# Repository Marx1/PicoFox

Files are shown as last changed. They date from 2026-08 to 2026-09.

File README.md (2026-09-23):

# PicoFox – A Hackable 2m Fox Transmitter
**Pacificon Edition**

*This version is modified from the original by AI6YM. It's designed to be a badge (Defcon/Ham Radio Village Style), doesn't have the expansion header, and runs sightly diffrent firmware.*

----------
**Partially AI CODED**
The modifications to this code was mainly done with AI. I want to be clear about this. 
I'm not a full-time coder, I do understand code, and don't have time to learn this platform for this one-off project.
I *HATE* when people pass off code as theirs when it's been AI/Vibe coded, so I wanted to be super clear here.
I did verify everything and validate the RF purity on my IFR 1900. It is a bit heavy on the deviation, so if you need it to be  more narrow, adjust AUDIO_FM_DEVIATION_HZ and SSTV_FM_DEVIATION_HZ as needed.
-- Trevor KG6MDW

----------

**PicoFox** is an open source fox transmitter for the 2-meter amateur band, built around the
RP2040 microcontroller (the same chip used in the Raspberry Pi Pico). It’s designed to be simple,
functional, and easy to modify.

PicoFox works well as a standalone fox for portable or walking hunts, but it’s also a great platform
for experimentation. There's ample CPU, flash,~~and GPIO~~ available if you want to add features ~~like
sensors or interactivity~~. The transmitter can generate a frequency or phase modulated signal with up
to 3kHz (data) bandwidth.

## Key Features
- Transmits FM in the 144–148 MHz band (ITU Zone 1: 144–146 MHz).
- Configured by editing a text file — no software or terminal needed.
- Transmits 8kHz 16-bit PCM WAV files.
- Automatic Morse code ID with configurable tone and speed.
- RF output > 18dBm at full power. Down to ~ -20dBm with full attenuation.
- Charges over USB.

## Extra Features in the Pacificon Firmware
- Built-in SSTV and APRS transmissions directly from JPEG and text files.
- RTTTL ringtone/song playback from a text file.
- Automatic cycling through WAV, RTTTL, JPEG, and APRS message files.
- Interleaves enabled Voice/Audio, SSTV, and APRS transmission modes.
- Dynamic TX power with a random attenuation value selected within a configured range for each transmission.
- Configurable transmit duty cycle based on the average TX time of recent transmissions.

## REMOVED Features in This Version:
- Expansion header

### Getting One

~~Fully assembled PicoFox units are available from [AI6YM.radio](https://ai6ym.radio/picofox). An
enclosure, battery, and antenna are included. I ship nearly anywhere in the world.~~

You can also build your own - both the hardware and software are open source for non-commercial use.
For commercial inquiries, I am not providing ANY production of the hardware. However for the original design contact [justin@ai6ym.radio](mailto:justin@ai6ym.radio), then load the firmware from this repository.

## Configuration

To configure your PicoFox, connect it to any computer using a micro USB cable. It will appear as a
USB mass storage device (like a flash drive). Open `settings.txt` with a text editor and adjust the
configuration values as needed. Eject the drive, disconnect USB, and power cycle the PicoFox to
apply the new settings.

To reset to factory settings, delete `settings.txt`, eject the drive, disconnect USB, and power
cycle the PicoFox. A default settings file will be regenerated.

### Settings Overview

__THIS SECTION IS STILL UNDER DEVELOPMENT AS THE NEW SOFTWARE IS BEING WRITTEN STILL__

- `CALLSIGN`: Alphanumeric callsign (max 12 characters).
- `ITU_ZONE`: ITU zone where the transmitter operates (`1`, `2`, or `3`).
- `FREQ_MHZ`: Transmit frequency in MHz.
- `DUTY_CYCLE`: Transmit duty cycle percentage (`0–100`). If SSTV mode is on, this must be < 80.
- `ATTENUATION_MODE`: Sets the attenuation mode. `FIXED` uses the `ATTENUATION` setting, `RANDOM` selects a random attenuation value on each transmission.
- `ATTENUATION`: Attenuation level used when `ATTENUATION_MODE=FIXED`. Valid range is `0` - `127`, approximately 0.25dB steps.
- `ATTENUATION_MIN`: Minimum attenuation value used when `ATTENUATION_MODE=RANDOM`. Valid range is `0` - `127` and must be less than `ATTENUATION_MAX`.
- `ATTENUATION_MAX`: Maximum attenuation value used when `ATTENUATION_MODE=RANDOM`. Valid range is `0` - `127` and must be greater than `ATTENUATION_MIN`.
- `FREQUENCY_SHIFTING`: Enables/Disables shifting of the carrier (+/-1k, +/-3k, +/-5k) for Wav/RTTTL transmissions. Does not affact SSTV/ARPS. Default is enabled.
- `MORSE_WPM`: Morse ID speed in words per minute. Maximum is 60wpm, default is 15wpm
- `MORSE_TONE`: Morse tone frequency (100–2000 Hz). Default is 600
- `MORSE_TONE_VOL`: Morse tone volume percentage (`1–100`). Default is 60. Over 60 may cause distortion. Adust as needed to make the Morse sound good.
- `VOICE_ENABLE`: Enables the Voice/Audio file.
- `MORSE_MESSAGE_ENABLE`: Enables Mose code message mode. Messages are read from `morse.txt` one message per line.
- `AUDIO_MODE`: Selects the normal audio source. `WAV` uses `audio.wav`, `audio1.wav`, `audio2.wav`, etc. `RTTTL` uses songs from `songs.txt`.
- `SSTV_ENABLE`: Enables SSTV Mode - YOU MUST set a duty cycle < 80 for this mode to work.
- `SSTV_MODE`: SSTV encoding mode, currently ONLY `ROBOT36` is supported.
- `APRS_ENABLE`: Enables APRS message transmissions. Messages are read from `messages.txt`, one message per line.

**Note:** Invalid or missing values may disable the transmitter or revert to safe defaults.

## Using the Transmitter

After configuring settings as described above. The transmitter will turn on following the
provided settings the next time it is turned on.

The transmitter may be powered by an external USB power supply or the internal battery. The internal
battery charges over USB but no indication is available to show battery charging.

**Note: The power switch must be ON to charge the battery over USB. The transmitter will run on USB
power with the switch OFF but the battery will NOT be charged.**

A full battery will last about five hours at 100% duty cycle with at 1200mAH battery. (The default for a PicoFox)

Transmit cycle is:
  - SSTV (If enabled)
  - APRS (If Enabled)
  - Audio/Morse Message

## Replacing the Audio File

To change the audio transmission, replace the `audio.wav` file in the device’s flash storage. The
audio must be sampled at **8kHz**, **mono** (one channel), and encoded as **signed 16-bit PCM WAV**.

*Note: Audio does not sound very good. I recomend using RTTTL.*

Using **Audacity** (free software available for all major OSs):

1. Set "Project Rate (Hz)" to `8000`.
2. Import, record, or generate your audio.
3. Mix down to a single mono track.
4. Export as WAV using **Signed 16-bit PCM** encoding.
5. Name the file `audio.wav` and copy it to the device.
6. Eject the drive and disconnect USB.
7. Power cycle the PicoFox.

**Notes:**

- Improper format may prevent audio transmission or cause noise to be transmitted instead.
- The audio is transmitted, followed by the morse ID, and then the transmitter turns off if
  `DUTY_CYCLE < 100`. The transmitter DOES take into account SSTV transmit times, as well as APRS.
- To restore the default audio, delete all  `audio.wav`, eject the drive, disconnect USB, and power cycle
  the PicoFox.
- To use muliple audio files, append a 1 to the file name. IE `audio1.wav`, `audio2.wav` etc.
- `FREQUENCY_SHIFTING` can cause the audio to sound bad. This causes the carrier to shift around a bit to make it a bit harder to find the fox.

## SSTV Mode

To use SSTV mode, Upload 320x240 JPEG images named `sstv.jpg` to the flash, and enable SSTV_MODE in the config file.

Make sure you have a valid callsign hard baked into your images. They should be 100% ready to transmit. the Picofox will NOT send a morse ID after SSTV.

**Notes:**
- To use muliple SSTV files, add sditional files with sqequencial numbers to the file name. IE `sstv.jpg`, `sstv1.jpg`, `sstv2.jpg` etc.
- The image MUST be 320x240 otherwise it will skip it.
- Due to timings etc, you may need to use auto-slant or high-precision slant correction. Some android apps (IE Robot36) seem to be OK
- DO NOT use a 100% duty cycle. there needs to be a break inbetween for the Pico to load the image. 99% should be fine if you want basically constant tx. In reality a lower duty cycle like 20-40% is better for harder hunts.

## APRS Mode

To use APRS mode, Upload a text file  named `message.txt` to the flash with a message on each line. To comment out a line use a #. this also means you can't just send a hashtag message. Enable `APRS_ENABLE` in the config file to transmit this mode.

The APRS messages are sent as a plain APRS message sent from the callsign configured in the config file and sent as a broadcast/beacon.  

__DO NOT USE THIS ON 144.39mhz Use a simplex/fox frequency.__

**Notes:**
- The messages are sent DIRECT so they wont be digipeated.

## Morse message Mode

Morse message mode lets you add an extra mose message  before it does the callsign. You can turn off Voice/RTTTL and it will do morse only; or leave voice/rttl on and it will do a voice/rttl -> Morse message -> callsign

To use Morse message mode, Upload a text file  named `message.txt` to the flash with a message on each line. To comment out a line use a #. this also means you can't just send a hashtag message. Enable `MORSE_MESSAGE_ENABLE` in the config file to transmit this mode.

## Random TX power / Attenuation

Included in the config is e settings: `ATTENUATION_MODE` , `ATTENUATION_MIN` and `ATTENUATION_MAX`

if `ATTENUATION_MODE` is set to `RANDOM` on each transmit a random atteunation value will be chosen between `ATTENUATION_MIN` and `ATTENUATION_MAX` and applied to the transmission..

## RTTTL Mode

This was inspired by a discussion had on the [Ham Radio Village](http://hamradiovillage.org/) Discord with delphi and Ralph in #software-shenanigans.

This is built from code from [EvilMog's RTTTL](https://github.com/evilmog/evilmog/tree/master/midijunk) work. As well as others.

To use this mode, enable it, and modify the `VOICE_ENABLE` to `1` and set `AUDIO_MODE` to `RTTTL`.
Then restart. This will create `songs.txt` 

To add songs/tunes, add a song per line following the FlipperMusicTTL format:

FlipperMusicTTL Format

You fan find details of this here, as well as example tunes: https://github.com/neverfa11ing/FlipperMusicRTTTL and https://1j01.github.io/rtttl.js/, you can also adapt some from websites like https://rtttl-hub.io/

**NOTES:**
- `FREQUENCY_SHIFTING` can cause the audio to sound bad. This causes the carrier to shift around a bit to make it a bit harder to find the fox.

## Design Brief

An SI5351 clock generator, locked to a TCXO, provides the RF signal. Modulation is applied in
software by the RP2040. To achieve smooth FM output, modulation is handled on core 1 with
I<sup>2</sup>C running at 1 MHz. Register writes are minimized and no other devices are on
I<sup>2</sup>C0.

Core 0 manages flash operations. Most extensions or new features should run on core 0.

**Note:** Mounting the device as a USB mass storage device will interrupt clean modulation as both
cores are blocked during flash operations. You will need to reset the device after writing to the file system.

The SPI flash device is split into program memory and a FAT16 filesystem. The filesystem contains
a text file for user-supplied settings, an audio file for transmission, and a hash file used to detect changes to the settings file.
Unexpected files are automatically deleted and missing files are re-created from defaults in the
firmware binary.

The design intentionally includes large amounts of free CPU cycles, RAM, and flash so that cool
things can be built on the PicoFox.

## Development Guide

### Build Environment Setup

- Install Arduino IDE >= 2.3.
- Install libraries - Adafruit SPIFlash, Adafruit TinyUSB, Etherkit Si5351.
- Install board package from [my fork of Arduino-Pico](https://github.com/ai6ym/arduino-pico). This
  will be merged upstream eventually but for now you'll need the changes in my fork.
- In `Tools -> Board` select the `Raspberry Pi RP2040/RP2350 Boards -> AI6YM PicoFox`.
- Connect your PicoFox and select the appropriate TTY / COM port.

On Linux it may be necessary to add udev rules for this device. The relevant rules from my system
are below. I have no idea how this works on other operating systems. Mac is probably similar,
Windows should not be used for software developement of any kind (or really anything).

```
# Make an RP2040 in BOOTSEL mode writable by all users, so you can `picotool`
# without `sudo`. 
SUBSYSTEM=="usb", ATTRS{idVendor}=="2e8a", ATTRS{idProduct}=="0003", MODE="0666"

# Symlink an RP2040 running MicroPython from /dev/pico.
#
# Then you can `mpr connect $(realpath /dev/pico)`.
SUBSYSTEM=="tty", ATTRS{idVendor}=="2e8a", ATTRS{idProduct}=="0005", SYMLINK+="pico"

# Adafruit TinyUSB stack.
SUBSYSTEM=="tty", ATTRS{idVendor}=="239a", ATTRS{idProduct}=="cafe", MODE="0666"
SUBSYSTEM=="usb", ATTRS{idVendor}=="239a", ATTRS{idProduct}=="cafe", MODE="0666"
```

### Compilation Settings

- `Flash Size`: `16MB (Sketch: 1MB, FS: 15MB)`
- `CPU Speed`: `200mhz`
- `USB Stack`: `Adafruit TinyUSB`

If needed for some reason you could change the partition layout to give more space for the sketch.
Doing so would destroy all data but the code automatically formats the partition and writes
defaults.

All other settings are fine at default values.

### Recovering a Board/Flashing manually (IE from one of the release files)

In general the UF2 upload process will work fine. Click the upload button, after compilation the IDE
will push the board into UF2 update mode, write the new binary, and then reset the board to normal
operation.

If that doesn't work try the following:
- Reset the board and try again. Just tap the `RESET` button on the board to reset the RP2040.
- Force the device into `BOOTSEL` mode. Hold the `BOOTSEL` button, tap the `RESET` button, and then
  release the `BOOTSEL` button.
- Force the device into `BOOTSEL` mode **AND** change `Tools -> Upload Method` to `PicoTool`.
- When all else fails grab a PicoProbe (or a Pico / Pico2 flashed with the PicoProbe binary),
  connect that to the debug header of the PicoFox, and change `Tools -> Upload Method` to
  `Picoprobe`.
- If all of the above fails, well, he's dead Jim.

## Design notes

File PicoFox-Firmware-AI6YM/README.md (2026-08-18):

# PicoFox – FIRMWARE

A couple notes about the firmware.

To build this, follow the instructions in the main readme.md but you also need the board files from here: https://github.com/ai6ym/arduino-pico

You also need to manually update the python to the latest (as of this commit, that was 3.14.4) as there is a bug with the embeded version that breaks for fat16. You'll need to modify packages/package.pico.indel.template.json to point to a copy of the embedable files from python with no folders. 

I ended up doing this, then having to manually edit a bunch of files and it was a real PITA, IMO, but I'm not a coder so YMMV.

Therefore if you want to build the files on your on, have at it. I'm going to provide the .uf2 files of AI6YM's version pre-compled, and my version so you can flip back and forth.

-Trevor KG6MDW

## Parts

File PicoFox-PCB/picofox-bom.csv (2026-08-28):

Reference | Value | Datasheet | Footprint | Qty | DNP | Description | LCSC Part Number | Manufacturer part number | Manufacturer
BT2 | 3.7V |  | PicofoxLib:JST PH 2 Horizontal | 1 |  | Single-cell battery | C295747 | S2B-PH-SM4-TB(LF)(SN) | JST
C1,C22,C24 | 10nF |  | Capacitor_SMD:C_0402_1005Metric | 3 |  | Unpolarized capacitor, small symbol | C3834692 | GRM1555CYA103GE01D | muRata
C2,C3 | 15pF |  | Capacitor_SMD:C_0402_1005Metric | 2 |  |  | C1548 | 0402CG150J500NT | FH
C4,C23,C68 | 100pF |  | Capacitor_SMD:C_0402_1005Metric | 3 |  | Unpolarized capacitor, small symbol | C1546 | 0402CG101J500NT | FH
C5,C6,C7,C9,C11,C12,C13,C14,C15,C16,C17,C31,C33,C67 | 100nF |  | Capacitor_SMD:C_0402_1005Metric | 14 |  | Unpolarized capacitor, small symbol | C307331 | CL05B104KB54PNC | Samsung
C8,C10 | 1uF |  | Capacitor_SMD:C_0402_1005Metric | 2 |  |  | C52923 | CL05A105KA5NQNC | Samsung
C18,C21,C25,C28 | 24pF |  | Capacitor_SMD:C_0402_1005Metric | 4 |  | Unpolarized capacitor, small symbol | C1864480 | GCM1555C1H240FA16D | muRata
C19,C20,C26,C27 | 43pF |  | Capacitor_SMD:C_0402_1005Metric | 4 |  | Unpolarized capacitor, small symbol | C415393 | GJM1555C1H430FB01D | muRata
C29,C30,C32,C40,C58 | 10uF |  | Capacitor_SMD:C_0603_1608Metric | 5 |  |  | C96446 | CL10A106MA8NRNC | Samsung
D1 | H5VU06B |  | PicofoxLib:DFN0603-2L | 1 |  | Bidirectional transient-voltage-suppression diode, small symbol | C20615780 | H5VU06B | R+O
D2,D4,D5 | LED |  | PicofoxLib:LED 1206 Side View | 3 |  | Light emitting diode | C375479 | E6C1204URAC1UDA | EKINGLUX
D3 | 1N4148WS | https://www.vishay.com/docs/85751/1n4148ws.pdf | Diode_SMD:D_SOD-323 | 1 |  | 75V 0.15A Fast switching Diode, SOD-323 | C2128 | 1N4148WS | JSCJ
FB1,FB2,FB3 | 600 |  | Inductor_SMD:L_0402_1005Metric | 3 |  | Ferrite bead, small symbol | C76886 | BLM15AX601SN1D | muRata
J4 | Conn_Coaxial_Small |  | Connector_Coaxial:SMA_Samtec_SMA-J-P-H-ST-EM1_EdgeMount | 1 |  | coaxial connector (BNC, SMA, SMB, SMC, Cinch/RCA, LEMO, ...) | C5301850 | HYCW12-SMAW0863-1365B | HOAUC
J5 | USB-TYPE-C-018 (DEALON) | https://www.usb.org/sites/default/files/documents/usb_type-c.zip | PicofoxLib:USB_C_Receptacle_HCTL_HC-TYPE-C-16P-01A | 1 |  | USB 2.0-only 16P Type-C Receptacle connector | C2927038 | C2927038 | DEALON
L1,L3,L4,L6 | 68nH |  | Inductor_SMD:L_0402_1005Metric | 4 |  | Inductor, small symbol | C7427064 | AHW1005C-68NJTF | APV
L2,L5 | 75nH |  | Inductor_SMD:L_0402_1005Metric | 2 |  | Murata LQW15AW75NG80D | C1012782 | LQW15AW75NG80D | Murata
L7 | 270nH |  | Inductor_SMD:L_0402_1005Metric | 1 |  | Inductor | C22400372 | YWIF1005-R27K | YJYCOIN
Q1 | AO3407A | http://www.aosmd.com/pdfs/datasheet/AO3401A.pdf | Package_TO_SOT_SMD:SOT-23 | 1 |  | -4.0A Id, -30V Vds, P-Channel MOSFET, SOT-23 | C7436553 | AO3407A | FUXINSEMI
R1 | 100KR |  | Resistor_SMD:R_0402_1005Metric | 1 |  | Resistor | C25741 | 0402WGF1003TCE | UNI-ROYAL
R2,R8,R37,R38 | 10KR |  | Resistor_SMD:R_0402_1005Metric | 4 |  | Resistor | C25744 | 0402WGF1002TCE | UNI-ROYAL
R3,R4 | 33R |  | Resistor_SMD:R_0402_1005Metric | 2 |  |  | C25105 | 0402WGF330JTCE | UNI-ROYAL
R5,R6,R7,R36 | 1KR |  | Resistor_SMD:R_0402_1005Metric | 4 |  |  | C11702 | 0402WGF1001TCE | UNI-ROYAL
R9,R10 | 2.2KR |  | Resistor_SMD:R_0402_1005Metric | 2 |  | Resistor | C25879 | 0402WGF2201TCE | UNI-ROYAL
R12,R40 | 120R |  | Resistor_SMD:R_0402_1005Metric | 2 |  | Resistor | C25079 | 0402WGF1200TCE | UNI-ROYAL
R13,R14,R39 | 294R |  | Resistor_SMD:R_0402_1005Metric | 3 |  | Resistor | C852689 | RT0402BRD07294RL | YAGEO
R15 | 17.4R |  | Resistor_SMD:R_0402_1005Metric | 1 |  | Resistor - Thin Film | C284383 | ARG02FTC17R4 | Viking
R27,R28 | 5.11KR |  | Resistor_SMD:R_0402_1005Metric | 2 |  |  | C5126228 | FRC0402F5111TS | FOJAN
SW1,SW2 |  |  | Button_Switch_SMD:SW_Push_SPST_NO_Alps_SKRK | 2 |  | Push button switch, generic, two pins | C720477 | TS-1088-AR02016 | XUNPU
SW3 | SK-12D15-G030 |  | PicofoxLib:SW_Slide_SPDT_Angled_CK_OS102011MA1Q | 1 |  | Switch, single pole double throw | C7544904 | SK-12D15-G030 | G-Switch
U1 | BVA1761 |  | Package_DFN_QFN:QFN-24-1EP_4x4mm_P0.5mm_EP2.5x2.5mm | 1 |  | Berex BVA1761 | C38240054 | BVA1761 | BeRex Corp
U2 | W25Q128JVS | http://www.winbond.com/resource-files/w25q128jv_dtr%20revc%2003272018%20plus.pdf | Package_SO:SOIC-8_5.23x5.23mm_P1.27mm | 1 |  |  | C97521 | W25Q128JVSIQ | Winbond
U3 | RP2040 |  | RP2040_minimal:RP2040-QFN-56 | 1 |  |  | C2040 | RP2040 | Raspberry Pi
U4 | Si5351A-B-GT | https://www.silabs.com/documents/public/data-sheets/Si5351-B.pdf | Package_SO:MSOP-10_3x3mm_P0.5mm | 1 |  | I2C Programmable Any-Frequency CMOS Clock Generator, MSOP-8 | C504891 | SI5351A-B-GTR | SILICON LABS
U15 | USBLC6-2SC6 | https://www.st.com/resource/en/datasheet/usblc6-2.pdf | Package_TO_SOT_SMD:SOT-23-6 | 1 |  | Very low capacitance ESD protection diode, 2 data-line, SOT-23-6 | C5180249 | USBLC6-2SC6-ES | ElecSuper
U16 | BQ21040DBVR | http://www.ti.com/lit/gpn/bq21040 | PicofoxLib:SOT95P280X145-6N | 1 |  | 0.8A Single Input Single-Cell Li-Ion and Li-Pol Battery Charger | C202311 | BQ21040DBVR | TI
U19 | ME6217C33M5G | https://jlcpcb.com/api/file/downloadByFileSystemAccessId/8588884515300892672 | Package_TO_SOT_SMD:SOT-23-5 | 1 |  | -40℃~+85℃ 1 100uA 180mV@(300mA) 3.3V 6.5V 65dB@(1kHz) 800mA Fixed Over Temperature Protection Positive SOT-23-5 Voltage Regulators - Linear, Low Drop Out (LDO) Regulators ROHS | C427602 | ME6217C33M5G | MICRONE
Y1 | ABM8-272-T3 |  | Crystal:Crystal_SMD_3225-4Pin_3.2x2.5mm | 1 |  |  | C20625731 | ABM8-272-T3 | ABRACON
Y2 | TG2016SMN_25.0000M-MCGNNM0 | https://www.mouser.in/datasheet/2/137/TG2016SMN_en-2584166.pdf | AI6YM:TG2016SMN250000MMCGNNM0 | 1 |  | TCXO Oscillators TG2016SMN 25.0000M-MCGNNM0: TCXO 2.8V 3.3V 0.5PPM -40 85C NON O/E 1K TR | C20340789 | TG2016SMN 25.0000M-MCGNNM0 | EPSON

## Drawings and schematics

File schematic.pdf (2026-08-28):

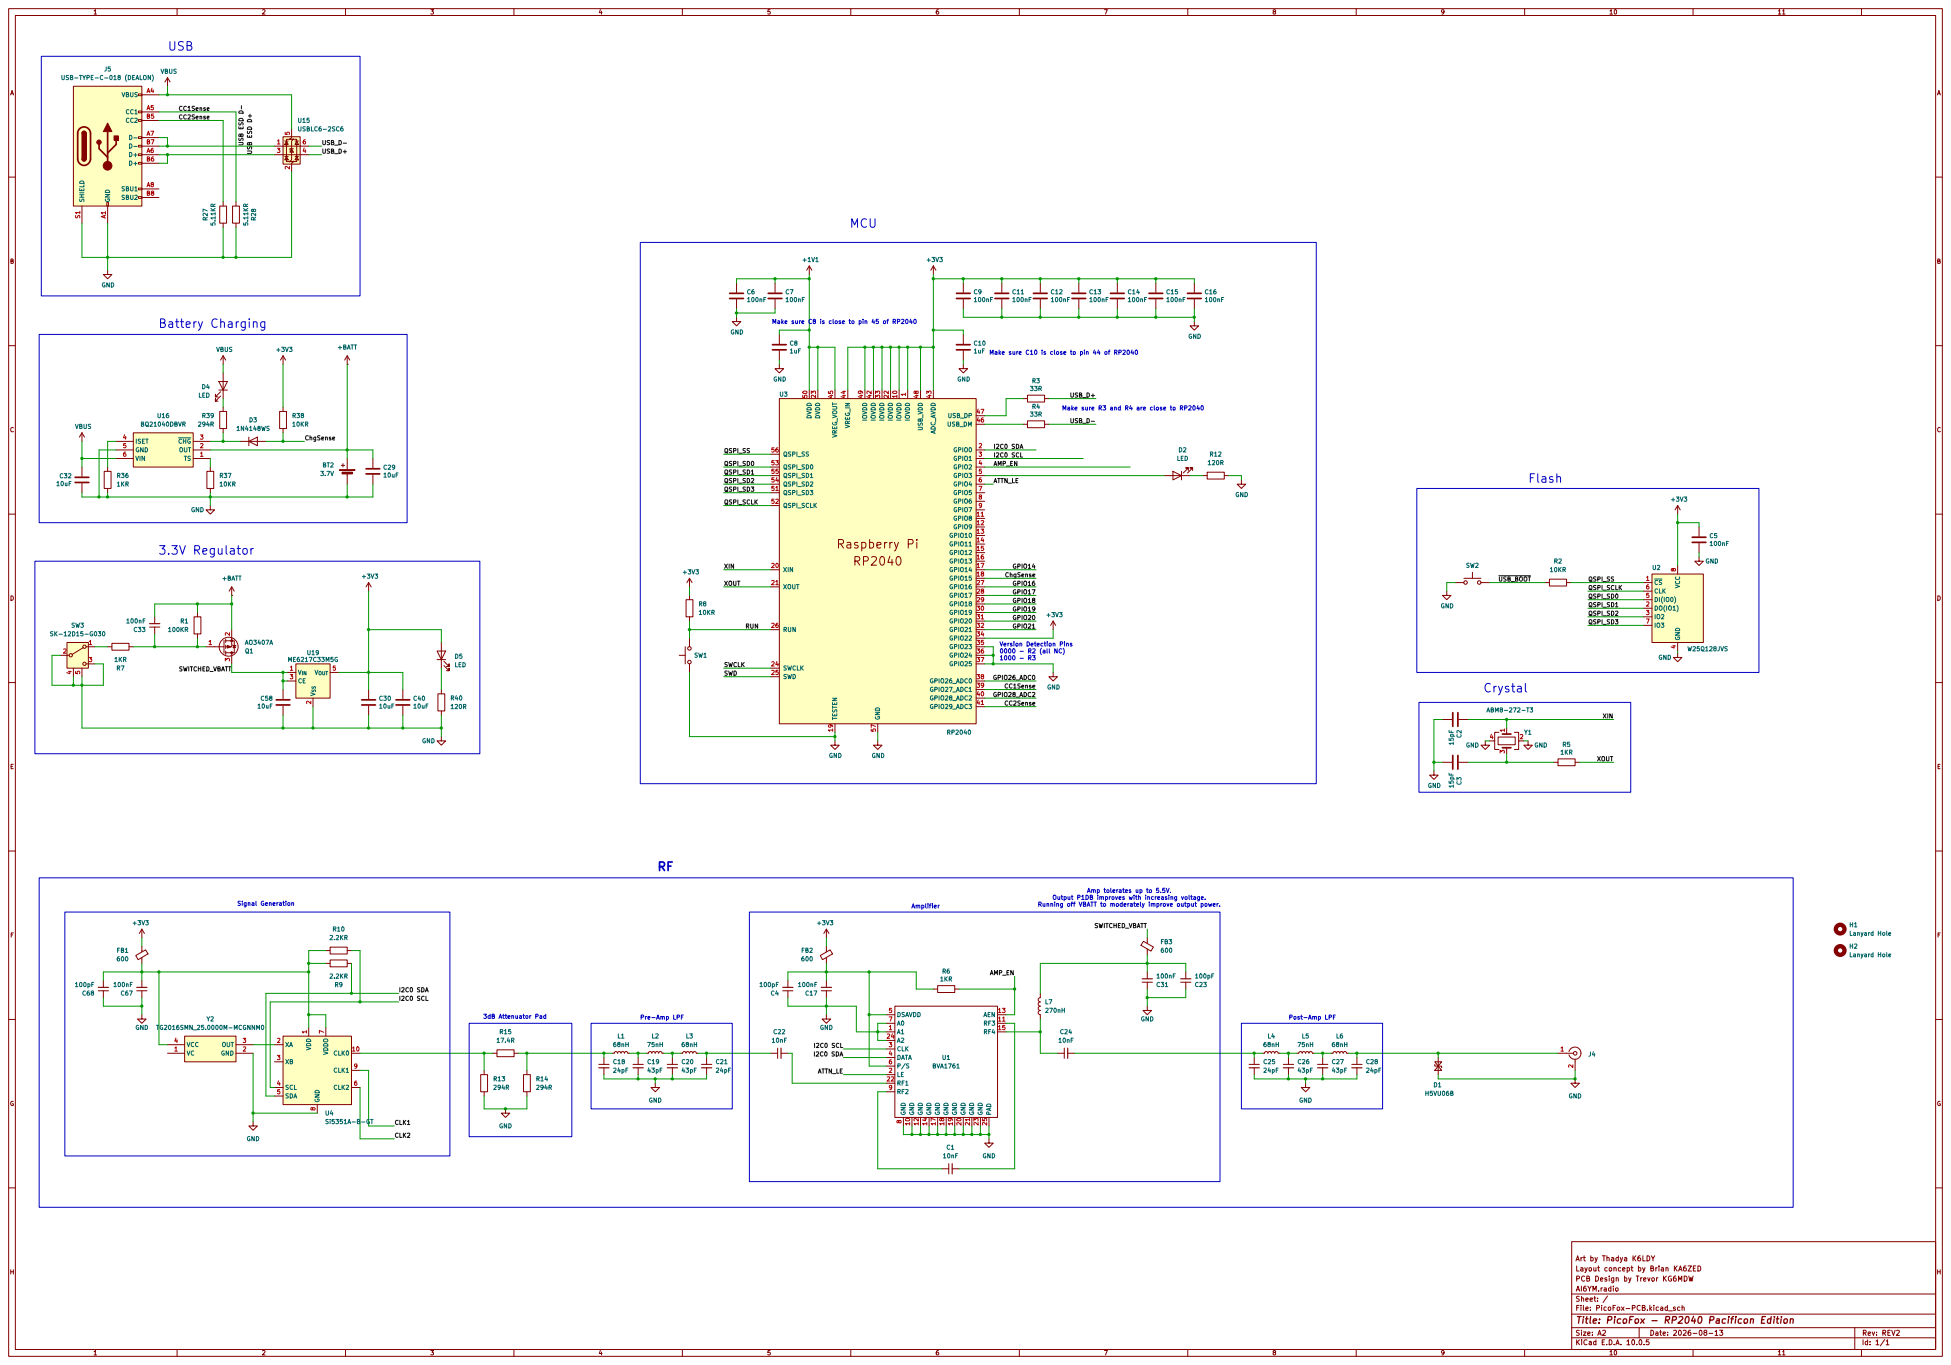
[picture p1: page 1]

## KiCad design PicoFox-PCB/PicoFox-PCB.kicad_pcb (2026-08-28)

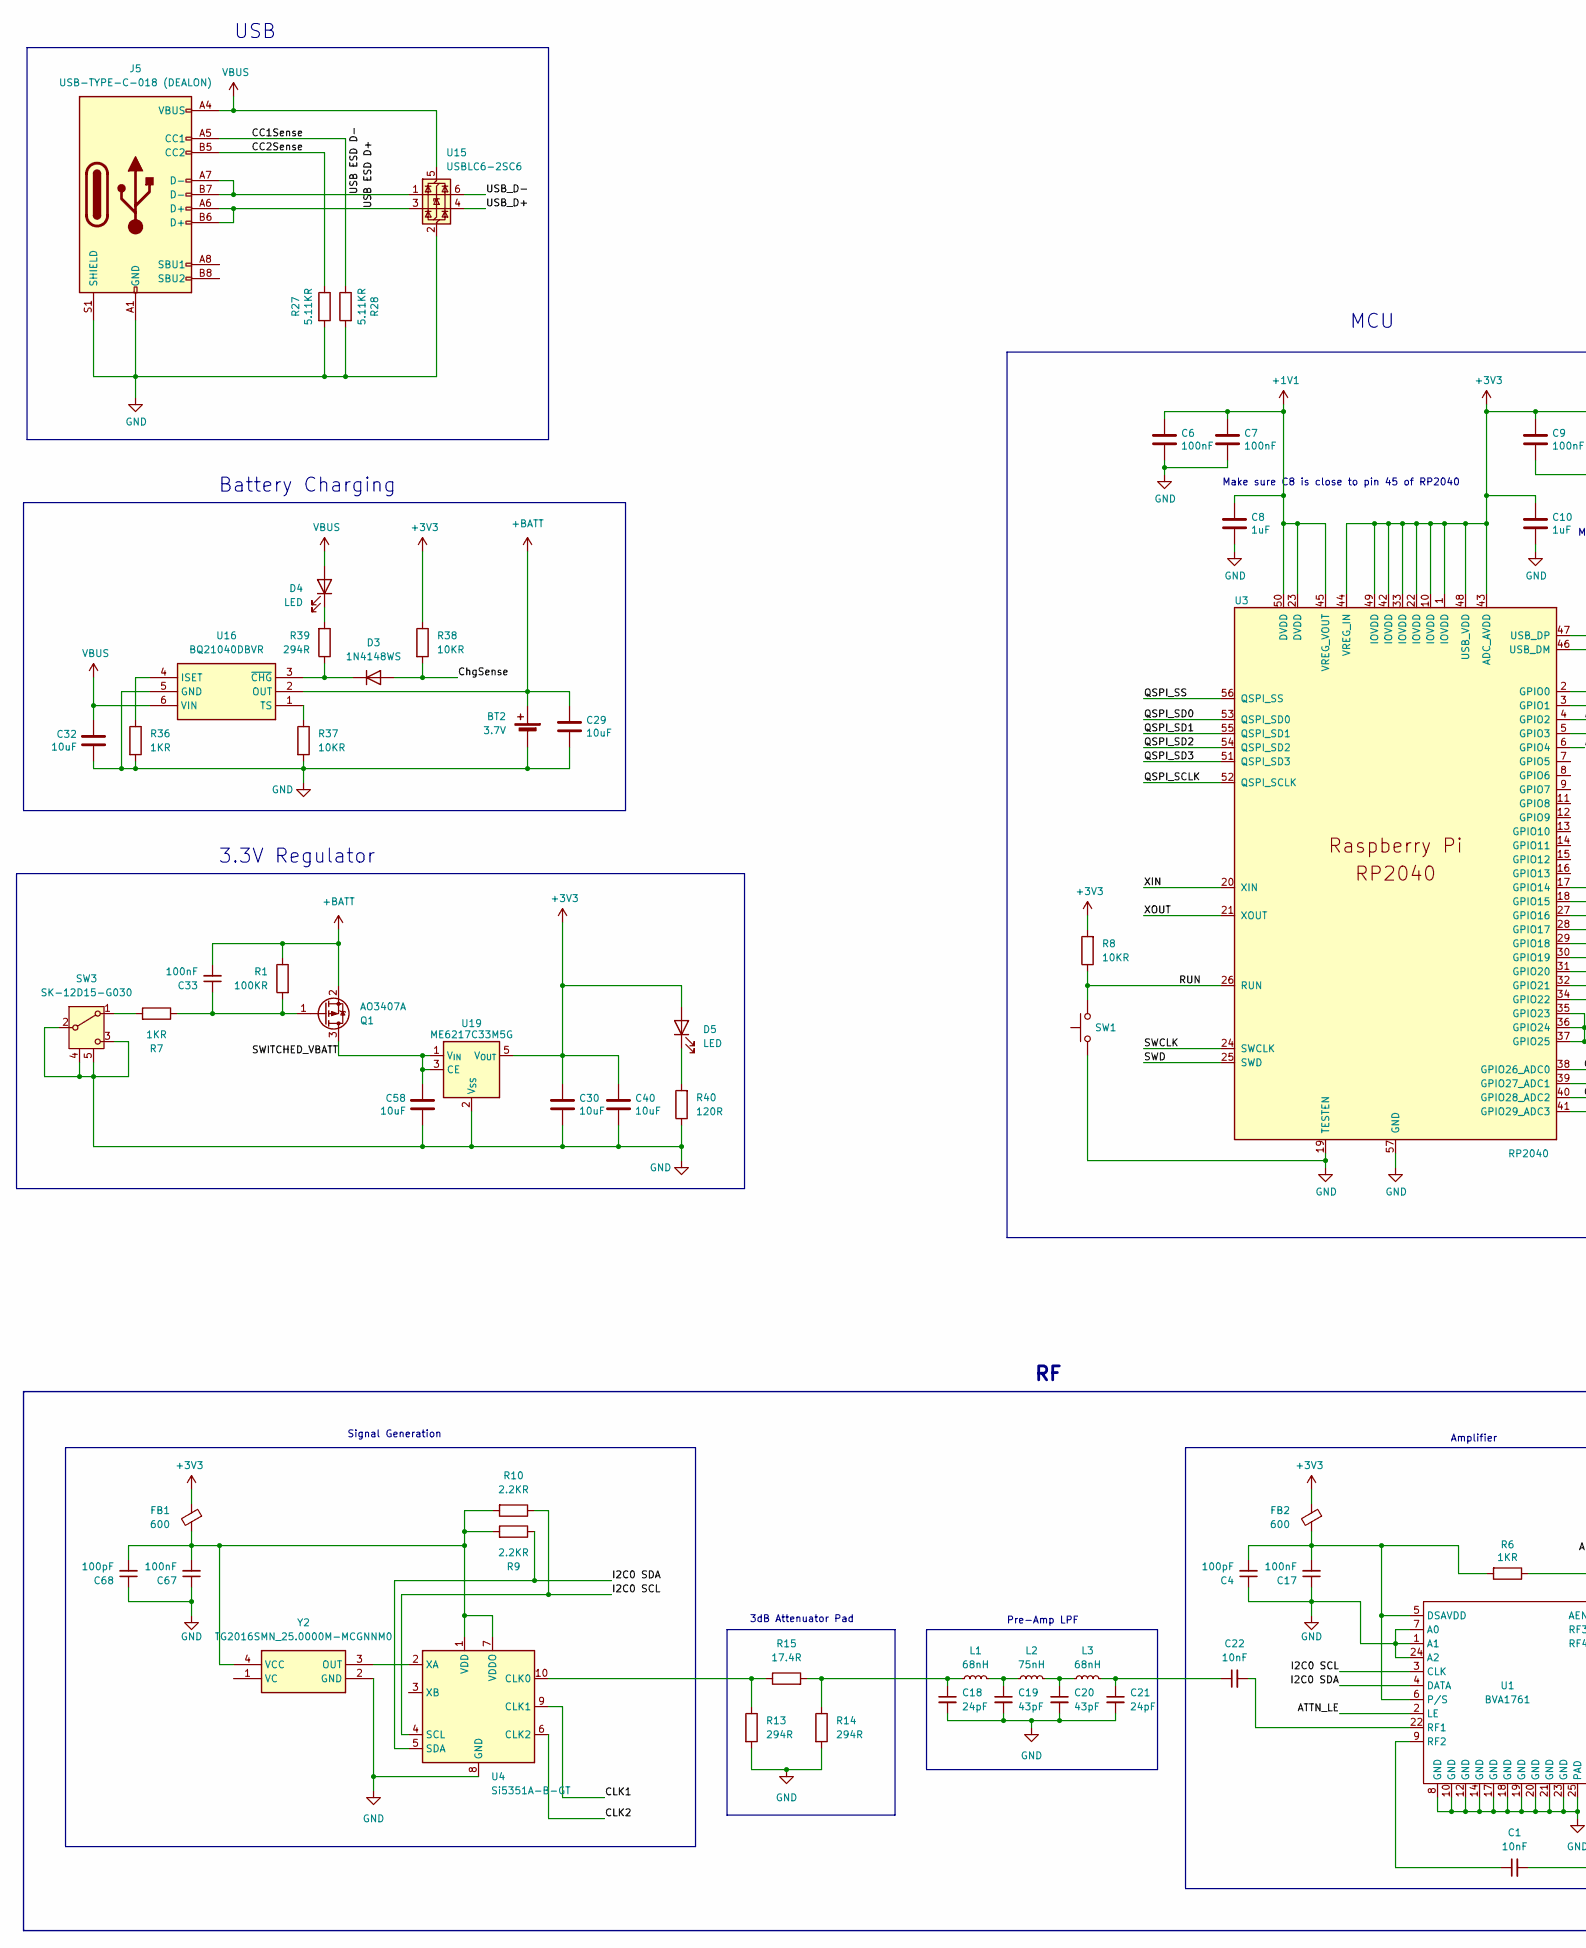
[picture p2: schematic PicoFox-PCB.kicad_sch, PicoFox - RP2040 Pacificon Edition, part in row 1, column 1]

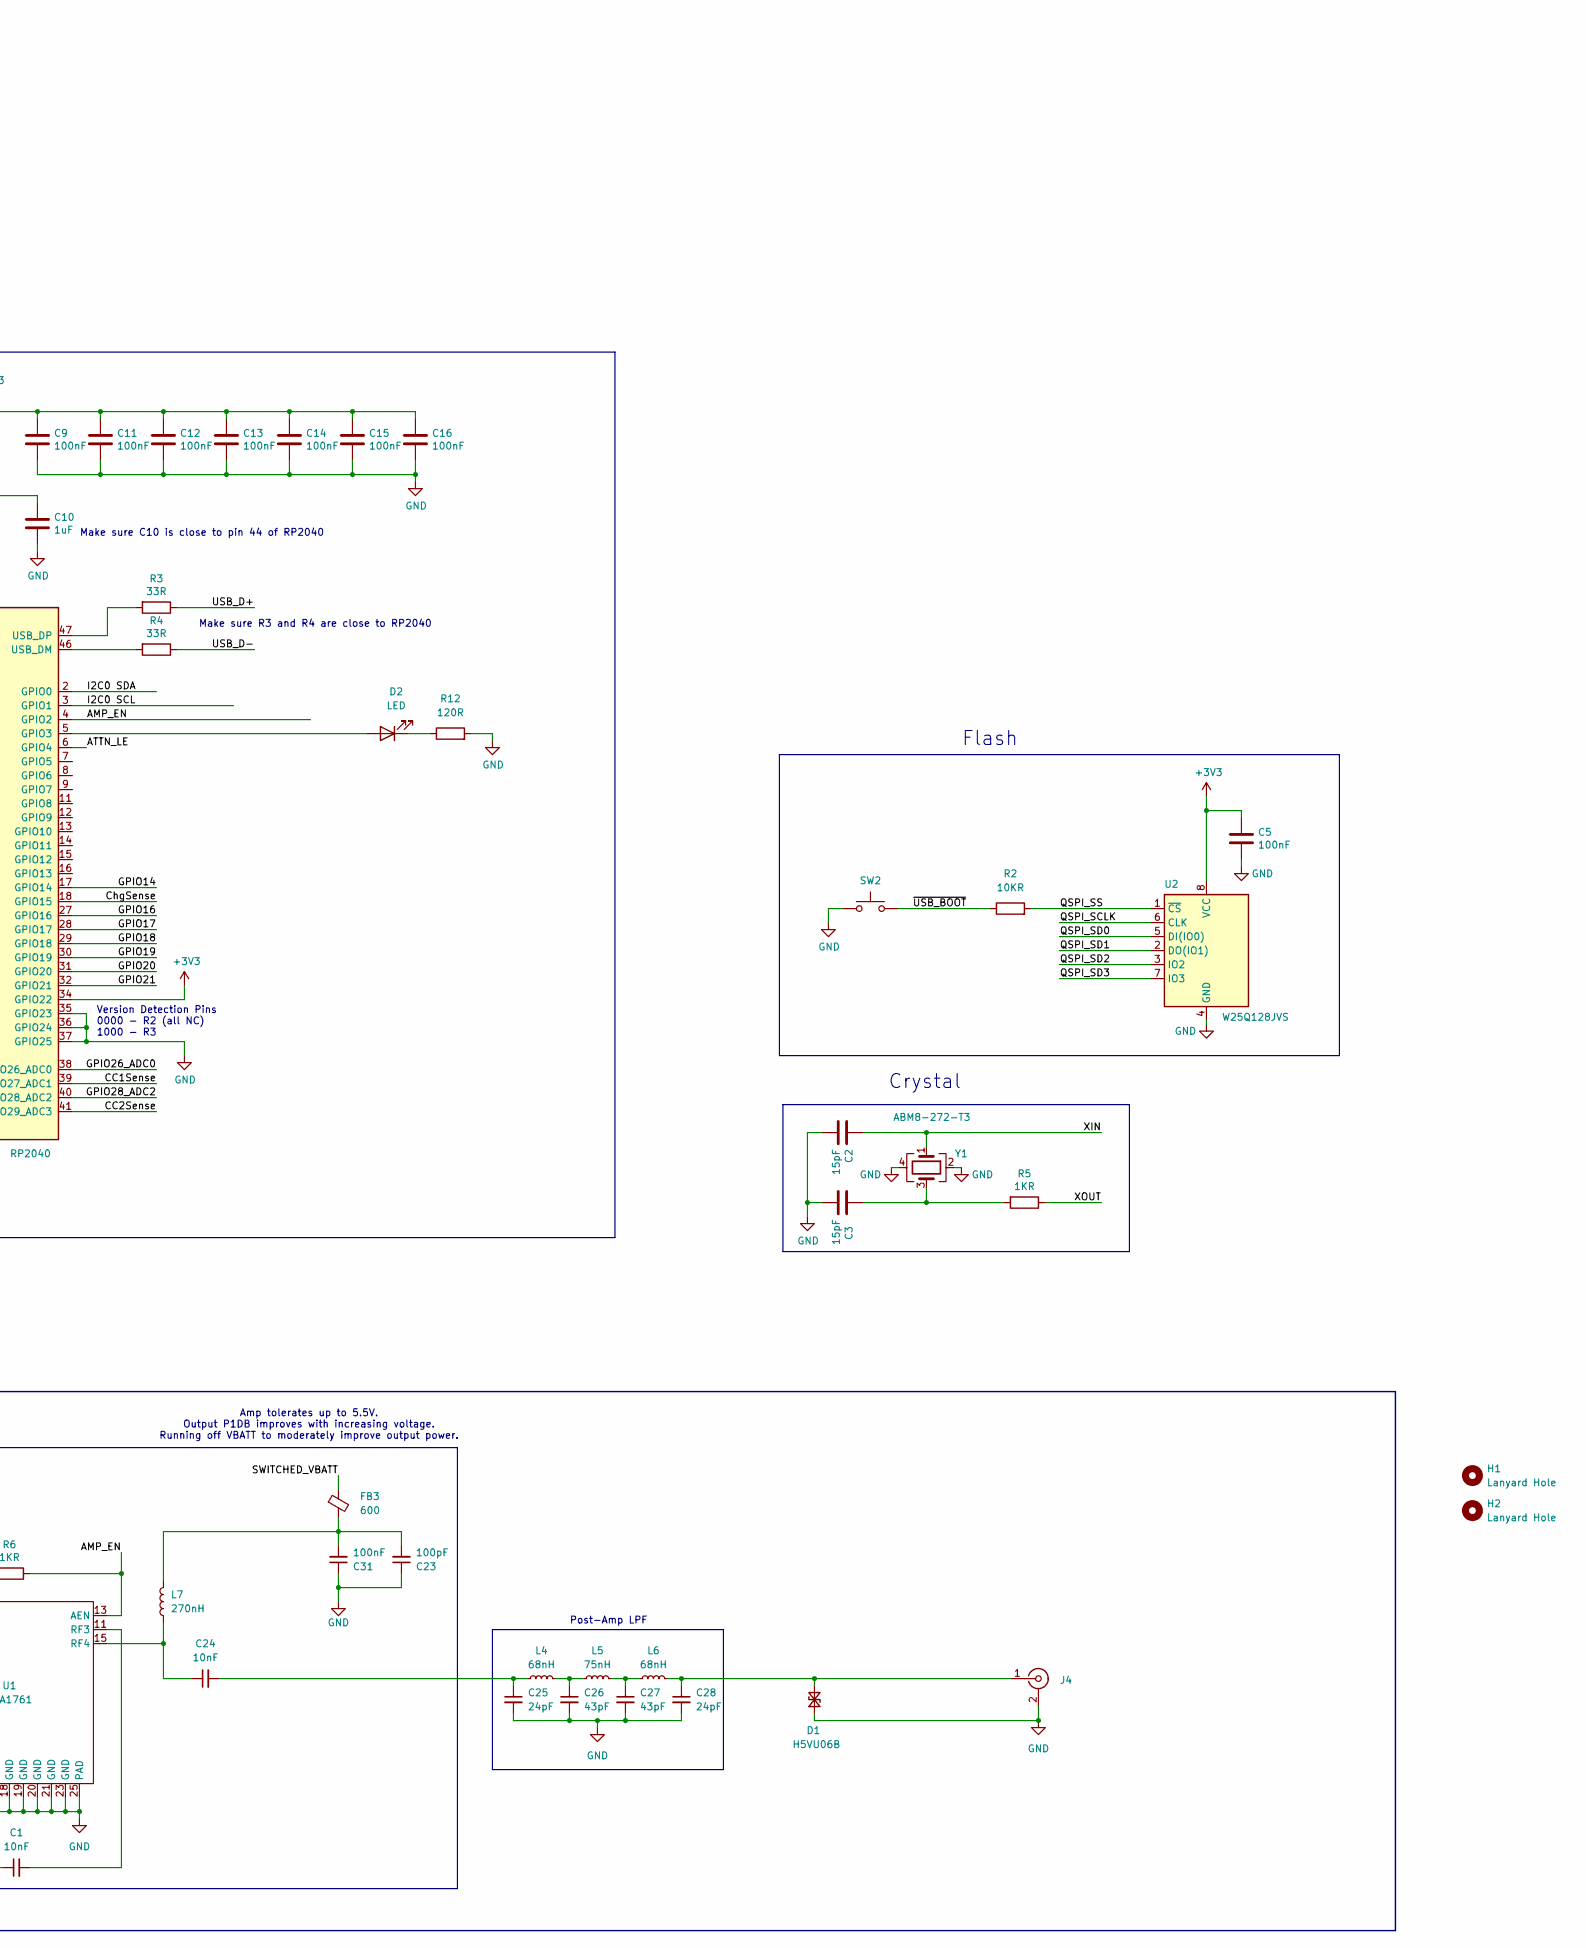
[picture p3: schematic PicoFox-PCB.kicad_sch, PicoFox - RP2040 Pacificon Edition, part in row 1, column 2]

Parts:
BT2: 3.7V; JST PH 2 Horizontal; LCSC C295747
C1, C22, C24: 10nF; C_0402_1005Metric; LCSC C3834692
C2, C3: 15pF; C_0402_1005Metric; LCSC C1548
C4, C23, C68: 100pF; C_0402_1005Metric; LCSC C1546
C5, C6, C7, C9, C11, C12, C13, C14, C15, C16, C17, C31, C33, C67: 100nF; C_0402_1005Metric; LCSC C307331
C8, C10: 1uF; C_0402_1005Metric; LCSC C52923
C18, C21, C25, C28: 24pF; C_0402_1005Metric; LCSC C1864480
C19, C20, C26, C27: 43pF; C_0402_1005Metric; LCSC C415393
C29, C30, C32, C40, C58: 10uF; C_0603_1608Metric; LCSC C96446
D1: H5VU06B; DFN0603-2L; LCSC C20615780
D2, D4, D5: LED; LED 1206 Side View; LCSC C375479
D3: 1N4148WS; D_SOD-323; LCSC C2128
FB1, FB2, FB3: 600; L_0402_1005Metric; LCSC C76886
H1, H2: Lanyard Hole; MountingHole_4.3mm_M4_DIN965
J4: Conn_Coaxial_Small; SMA_Samtec_SMA-J-P-H-ST-EM1_EdgeMount; LCSC C5301850
J5: USB-TYPE-C-018 (DEALON); USB_C_Receptacle_HCTL_HC-TYPE-C-16P-01A; LCSC C2927038
L1, L3, L4, L6: 68nH; L_0402_1005Metric; LCSC C7427064
L2, L5: 75nH; L_0402_1005Metric
L7: 270nH; L_0402_1005Metric; LCSC C22400372
Q1: AO3407A; SOT-23; LCSC C7436553
R1: 100KR; R_0402_1005Metric; LCSC C25741
R2, R8, R37, R38: 10KR; R_0402_1005Metric; LCSC C25744
R3, R4: 33R; R_0402_1005Metric; LCSC C25105
R5, R6, R7, R36: 1KR; R_0402_1005Metric; LCSC C11702
R9, R10: 2.2KR; R_0402_1005Metric; LCSC C25879
R12, R40: 120R; R_0402_1005Metric; LCSC C25079
R13, R14, R39: 294R; R_0402_1005Metric; LCSC C852689
R15: 17.4R; R_0402_1005Metric; LCSC C284383
R27, R28: 5.11KR; R_0402_1005Metric; LCSC C5126228
SW1, SW2: SW_Push_SPST_NO_Alps_SKRK; LCSC C720477
SW3: SK-12D15-G030; SW_Slide_SPDT_Angled_CK_OS102011MA1Q; LCSC C7544904
U1: BVA1761; QFN-24-1EP_4x4mm_P0.5mm_EP2.5x2.5mm; LCSC C38240054
U2: W25Q128JVS; SOIC-8_5.23x5.23mm_P1.27mm; LCSC C97521
U3: RP2040; RP2040-QFN-56; LCSC C2040
U4: Si5351A-B-GT; MSOP-10_3x3mm_P0.5mm; LCSC C504891
U15: USBLC6-2SC6; SOT-23-6; LCSC C5180249
U16: BQ21040DBVR; SOT95P280X145-6N; Mouser Part Number 595-BQ21040DBVR
U19: ME6217C33M5G; SOT-23-5; LCSC C427602
Y1: ABM8-272-T3; Crystal_SMD_3225-4Pin_3.2x2.5mm; LCSC C20625731
Y2: TG2016SMN_25.0000M-MCGNNM0; TG2016SMN250000MMCGNNM0; Mouser Part Number 732-2016SMN25MCGNNM0

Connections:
+1V1: C6.1, C7.1, C8.1, U3.23 (DVDD), U3.45 (VREG_VOUT), U3.50 (DVDD)
+3V3: C5.1, C9.1, C10.1, C11.1, C12.1, C13.1, C14.1, C15.1, C16.1, C30.1, C40.1, D5.1 (A), FB1.1, FB2.1, R8.2, R38.1, U2.8 (VCC), U3.1 (IOVDD), U3.10 (IOVDD), U3.22 (IOVDD), U3.33 (IOVDD), U3.34 (GPIO22), U3.42 (IOVDD), U3.43 (ADC_AVDD), U3.44 (VREG_IN), U3.48 (USB_VDD), U3.49 (IOVDD), U19.5 (V_{OUT})
+BATT: BT2.1 (+), C29.1, C33.2, Q1.2 (S), R1.1, U16.2 (OUT)
/AMP_EN: R6.1, U1.13 (AEN), U3.4 (GPIO2)
/ATTN_LE: U1.2 (LE), U3.6 (GPIO4)
/CC1Sense: J5.A5 (CC1), R28.1, U3.39 (GPIO27_ADC1)
/CC2Sense: J5.B5 (CC2), R27.1, U3.41 (GPIO29_ADC3)
/CLK1: U4.9 (CLK1)
/CLK2: U4.6 (CLK2)
/ChgSense: D3.2 (A), R38.2, U3.18 (GPIO15)
/GPIO14: U3.17 (GPIO14)
/GPIO16: U3.27 (GPIO16)
/GPIO17: U3.28 (GPIO17)
/GPIO18: U3.29 (GPIO18)
/GPIO19: U3.30 (GPIO19)
/GPIO20: U3.31 (GPIO20)
/GPIO21: U3.32 (GPIO21)
/GPIO26_ADC0: U3.38 (GPIO26_ADC0)
/GPIO28_ADC2: U3.40 (GPIO28_ADC2)
/I2C0 SCL: R10.1, U1.3 (CLK), U3.3 (GPIO1), U4.4 (SCL)
/I2C0 SDA: R9.1, U1.4 (DATA), U3.2 (GPIO0), U4.5 (SDA)
/QSPI_SCLK: U2.6 (CLK), U3.52 (QSPI_SCLK)
/QSPI_SD0: U2.5 (DI(IO0)), U3.53 (QSPI_SD0)
/QSPI_SD1: U2.2 (DO(IO1)), U3.55 (QSPI_SD1)
/QSPI_SD2: U2.3 (IO2), U3.54 (QSPI_SD2)
/QSPI_SD3: U2.7 (IO3), U3.51 (QSPI_SD3)
/QSPI_SS: R2.2, U2.1 (~CS), U3.56 (QSPI_SS)
/RUN: R8.1, SW1.2, U3.26 (RUN)
/SWCLK: U3.24 (SWCLK)
/SWD: U3.25 (SWD)
/SWITCHED_VBATT: C58.1, FB3.1, Q1.3 (D), U19.1 (V_{IN}), U19.3 (CE)
/USB ESD D+: J5.A6 (D+), J5.B6 (D+), U15.3 (I/O2)
/USB ESD D-: J5.A7 (D-), J5.B7 (D-), U15.1 (I/O1)
/USB_D+: R3.1, U15.4 (I/O2)
/USB_D-: R4.1, U15.6 (I/O1)
/XIN: C2.1, U3.20 (XIN), Y1.1
/XOUT: R5.1, U3.21 (XOUT)
/~USB_BOOT: R2.1, SW2.2
GND: BT2.2 (-), C2.2, C3.2, C4.1, C5.2, C6.2, C7.2, C8.2, C9.2, C10.2, C11.2, C12.2, C13.2, C14.2, C15.2, C16.2, C17.1, C18.2, C19.2, C20.2, C21.2, C23.1, C25.2, C26.2, C27.2, C28.2, C29.2, C30.2, C31.1, C32.2, C40.2, C58.2, C67.1, C68.1, D1.1 (A1), J4.2 (Ext), J5.A1 (GND), J5.A12 (GND), J5.B1 (GND), J5.B12 (GND), J5.S1 (SHIELD), R12.2, R13.2, R14.2, R27.2, R28.2, R36.2, R37.2, R40.1, SW1.1, SW2.1, SW3.2 (B), SW3.3 (C), SW3.4 (SH), SW3.5 (SH), U1.1 (A1), U1.7 (A0), U1.8 (GND), U1.10 (GND), U1.12 (GND), U1.14 (GND), U1.17 (GND), U1.18 (GND), U1.19 (GND), U1.20 (GND), U1.21 (GND), U1.23 (GND), U1.24 (A2), U1.25 (PAD), U2.4 (GND), U3.19 (TESTEN), U3.35 (GPIO23), U3.36 (GPIO24), U3.37 (GPIO25), U3.57 (GND), U4.8 (GND), U15.2 (GND), U16.5 (GND), U19.2 (V_{SS}), Y1.2, Y1.4, Y2.2 (GND)
unnamed: C3.1, R5.2, Y1.3
unnamed: C18.1, L1.1, R14.1, R15.2
unnamed: C19.1, L1.2, L2.1
unnamed: C20.1, L2.2, L3.1
unnamed: C21.1, C22.1, L3.2
unnamed: C23.2, C31.2, FB3.2, L7.2
unnamed: C24.2, C25.1, L4.1
unnamed: C26.1, L4.2, L5.1
unnamed: C27.1, L5.2, L6.1
unnamed: C28.1, D1.2 (A2), J4.1 (In), L6.2
unnamed: D2.1 (A), U3.5 (GPIO3)
unnamed: D2.2 (K), R12.1
unnamed: D3.1 (K), R39.1, U16.3 (~CHG)
unnamed: D4.2 (K), R39.2
unnamed: D5.2 (K), R40.2
unnamed: C33.1, Q1.1 (G), R1.2, R7.1
unnamed: R7.2, SW3.1 (A)
unnamed: C4.2, C17.2, FB2.2, R6.2, U1.5 (DSAVDD), U1.6 (P/S)
unnamed: C22.2, U1.22 (RF1)
unnamed: C1.1, U1.9 (RF2)
unnamed: C1.2, U1.11 (RF3)
unnamed: C24.1, L7.1, U1.15 (RF4)
unnamed: R4.2, U3.46 (USB_DM)
unnamed: R3.2, U3.47 (USB_DP)
unnamed: R13.1, R15.1, U4.10 (CLK0)
unnamed: C67.2, C68.2, FB1.2, R9.2, R10.2, U4.1 (VDD), U4.7 (VDDO), Y2.4 (VCC)
unnamed: U4.2 (XA), Y2.3 (OUT)
unnamed: R36.1, U16.4 (ISET)
unnamed: R37.1, U16.1 (TS)
VBUS: C32.1, D4.1 (A), J5.A4 (VBUS), J5.A9 (VBUS), J5.B4 (VBUS), J5.B9 (VBUS), U15.5 (VBUS), U16.6 (VIN)

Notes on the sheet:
Amplifier
Battery Charging
Make sure C8 is close to pin 45 of RP2040
3.3V Regulator
Crystal
Pre-Amp LPF
Version Detection Pins 0000 - R2 (all NC) 1000 - R3
Make sure C10 is close to pin 44 of RP2040
Post-Amp LPF
Amp tolerates up to 5.5V. Output P1DB improves with increasing voltage. Running off VBATT to moderately improve output power.
Signal Generation
USB
Make sure R3 and R4 are close to RP2040
Flash
3dB Attenuator Pad
MCU

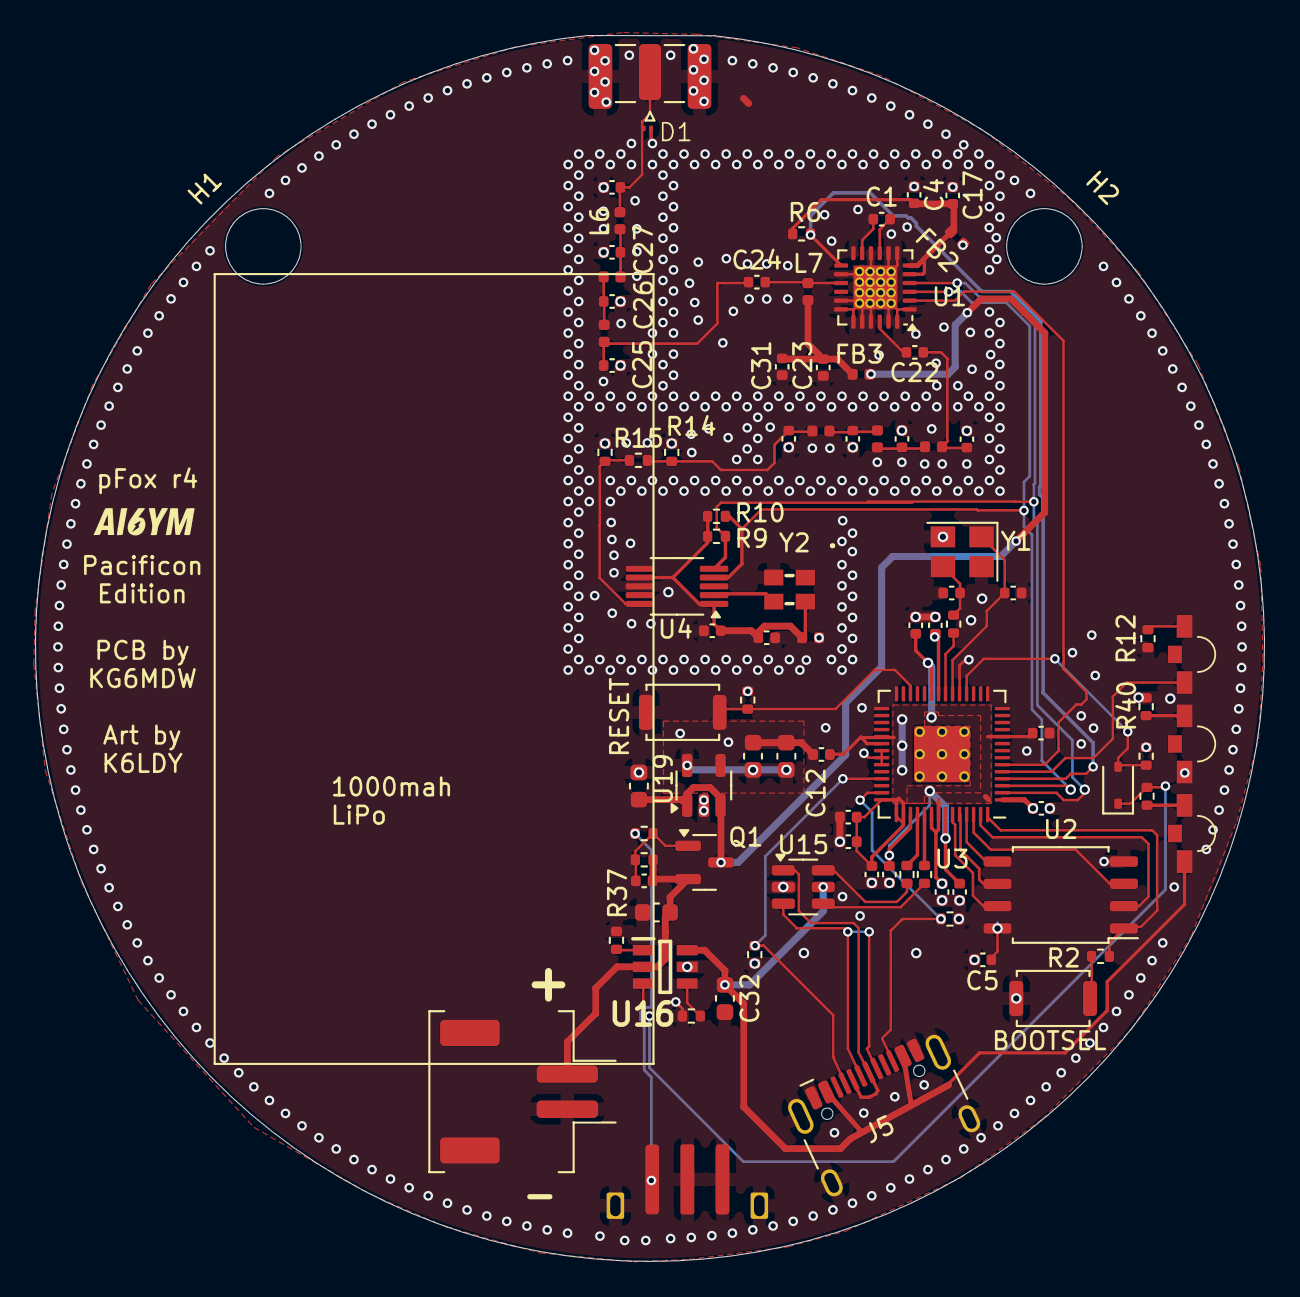
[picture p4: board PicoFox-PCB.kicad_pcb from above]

Board: 4 copper layers, 70.0 x 69.8 mm, 91 parts (0 on the bottom side), 56 nets.

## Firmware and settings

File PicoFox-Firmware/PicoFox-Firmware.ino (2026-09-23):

/*
  PicoFox - configurable frequency shifting v57
  Based on PicoFox firmware by Giorgi Enterprises LLC dba AI6YM.radio.
  Original project:
  https://github.com/Marx1/PicoFox

  Original license:
  Creative Commons Attribution-NonCommercial-ShareAlike 4.0 International.
  COMMERCIAL USE OF THIS CODE AND ANY DERIVATIVE IS FORBIDDEN WITHOUT
  PERMISSION FROM THE COPYRIGHT HOLDER.

  Stage 1:
    - Preserve flash contents across reboot. Flash is formatted only when mount fails.

  Stage 2:
    - Add SSTV_ENABLE and SSTV_MODE settings.

  Stage 3:
    - Add a real-time SSTV audio-tone DDS/NCO.
    - IMPORTANT: SSTV tone frequency is AUDIO frequency. A constant Si5351
      frequency offset would demodulate as DC, not as a 1200-2300 Hz SSTV tone.
      This code therefore synthesizes a sine-wave FM deviation just like PCM audio.

  Stage 4:
    - Add Robot 36 VIS/header and scan timing.
    - Measure Si5351 update duration, missed sample deadlines, and real frame time.
    - RF output remains disabled for 5 seconds after boot before any transmit.

  Arduino environment:
    - Earle Philhower RP2040 core
    - Etherkit Si5351
    - Adafruit SPIFlash
    - Adafruit TinyUSB
    - SdFat - Adafruit Fork
*/

/*
  RTTTL support in this firmware was inspired by and adapted from ideas in
  EvilMog's midijunk project:

  https://github.com/evilmog/evilmog/tree/master/midijunk

  Credit: EvilMog
*/



#include <Arduino.h>
#include <Wire.h>
#include <si5351.h>
#include "SPI.h"
#include "SdFat_Adafruit_Fork.h"
#include "Adafruit_SPIFlash.h"
#include "Adafruit_TinyUSB.h"
#include <JPEGDEC.h>


// #define DEBUG 1

// -----------------------------------------------------------------------------
// Hardware / original PicoFox constants
// -----------------------------------------------------------------------------

#define ID0 22u
#define ID1 23u
#define ID2 24u
#define ID3 25u

#define SDA 0u
#define SCL 1u
#define I2C_CLOCK_HZ 1000000

#define AMP_EN 2u
#define ATTN_LE 4u

#define AUDIO_SAMPLE_RATE_HZ 8000UL
#define AUDIO_FM_DEVIATION_HZ 5000
#define AUDIO_SAMPLE_PERIOD_US (1000000UL / AUDIO_SAMPLE_RATE_HZ)

// RF sequencing delays.
// Allow the transmitter/amplifier to settle before modulation begins.
#define TX_KEYUP_DELAY_MS 100UL

// Silent keyed-carrier gap between WAV/RTTTL audio and the live Morse ID.
#define AUDIO_TO_MORSE_GAP_MS 1000UL

// APRS / AX.25 1200-baud Bell 202 AFSK.
// 60 HDLC flags at 1200 baud provide a 400 ms preamble.
#define APRS_BAUD 1200UL
#define APRS_MARK_HZ 1200U
#define APRS_SPACE_HZ 2200U
#define APRS_PREAMBLE_FLAGS 60U
#define APRS_POSTAMBLE_FLAGS 3U
#define APRS_TONE_AMPLITUDE_PERCENT 60U

// RTTTL tone modulation level. Keep this below full-scale to reduce
// over-deviation/distortion on higher-pitched notes.
#define RTTTL_TONE_AMPLITUDE_PERCENT 60U
#define APRS_MAX_MESSAGE_LEN 67U

// Always leave at least this much RF-off time after an APRS packet before
// another transmission begins. The duty-cycle off time may make it longer.
#define APRS_POST_TX_GAP_MS 1000UL

// Duty-cycle timing is based on the average RF-on time of recent
// transmissions, then the same calculated OFF time is applied after every
// transmission mode. A rolling window lets the average adapt if song lengths
// or enabled modes change.
#define DUTY_AVERAGE_WINDOW 12U
#define SSTV_FM_DEVIATION_HZ 3000

#define SI5351_PLL SI5351_PLLA
#define SI5351_CLOCK_OUTPUT SI5351_CLK0
#define SI5351_PLL_HZ 900000000
#define SI5351_CLOCK_DIV 6

#define SI5351_DRIVE_LEVEL_R2 SI5351_DRIVE_2MA
#define SI5351_DRIVE_LEVEL_R3 SI5351_DRIVE_2MA

#define TEST_MODE_PIN 14u

#define MIN_FREQ_MHZ 144
#define MAX_FREQ_MHZ_ITU1 146
#define MAX_FREQ_MHZ 148

// -----------------------------------------------------------------------------
// SSTV stage 1-4 constants
// -----------------------------------------------------------------------------

// SSTV and normal audio now both use an 8 kHz modulation update rate.
// 10 kHz gives ~4.35 samples/cycle at the 2300 Hz video upper limit while
// NOTE: if the Si5351/I2C update cannot complete inside 100 us, decoded timing
// will run long. DEBUG timing can be added later to measure that directly.
#define SSTV_SAMPLE_RATE_HZ 8000UL
#define SSTV_SAMPLE_PERIOD_US (1000000UL / SSTV_SAMPLE_RATE_HZ)

// Keep the transmitter RF-silent briefly after power-up/reset.
#define BOOT_TX_DELAY_MS 5000UL

// Re-use the same FM deviation that the existing PCM player uses.
// This is the PEAK RF deviation of the synthesized audio sine wave.

// Timing-critical SSTV PLL path.
// The 8 kHz modulation loop has a 125 us sample period and the Si5351 I2C
// transaction consumes most of that budget. Keep filesystem access, Serial
// output, JPEG decoding, RGB conversion, floating-point work, and other
// variable-latency operations outside the real-time transmit loop.
#define SSTV_PLL_TABLE_LEVELS 512
#define AUDIO_PLL_TABLE_LEVELS 512
#define SI5351_I2C_ADDRESS 0x60
#define SI5351_PLLA_PARAMETERS_REG 26
#define SI5351_RFRAC_DENOM 1000000ULL
#define SI5351_REF_FREQ_X100 2500000000ULL

#define SSTV_MODE_ROBOT36 36
#define PICOFOX_FIRMWARE_VERSION "v64"
#define AUDIO_MODE_WAV 0
#define AUDIO_MODE_RTTTL 1

#define ATTENUATION_MODE_FIXED 0
#define ATTENUATION_MODE_RANDOM 1
#define DEFAULT_AUDIO_MODE AUDIO_MODE_WAV
#define DEFAULT_VOICE_ENABLE true
#define DEFAULT_SSTV_ENABLE false
#define DEFAULT_SSTV_MODE SSTV_MODE_ROBOT36

// SSTV standard tone frequencies.
#define SSTV_VIS_LEADER_HZ 1900
#define SSTV_VIS_BREAK_HZ 1200
#define SSTV_VIS_BIT_1_HZ 1100
#define SSTV_VIS_BIT_0_HZ 1300
#define SSTV_SYNC_HZ 1200
#define SSTV_BLACK_HZ 1500
#define SSTV_MID_HZ 1900
#define SSTV_WHITE_HZ 2300

// Robot 36 timing.
#define R36_WIDTH 256
#define R36_HEIGHT 240
#define R36_SYNC_US 9000UL
#define R36_SYNC_PORCH_US 3000UL
#define R36_Y_SCAN_US 88000UL
#define R36_SEPARATOR_US 4500UL
#define R36_CHROMA_PORCH_US 1500UL
#define R36_CHROMA_SCAN_US 44000UL

// VIS code for Robot 36.
#define R36_VIS_CODE 8

// -----------------------------------------------------------------------------
// Globals
// -----------------------------------------------------------------------------

bool test_mode = false;
uint16_t revision = 0;
bool wireRunning = false;

Si5351 si5351;

Adafruit_FlashTransport_RP2040 flashTransport;
Adafruit_SPIFlash flash(&flashTransport);

FatFormatter formatter;
FatVolume fatfs;
FatFile root;
FatFile file;

Adafruit_USBD_MSC usb_msc;
volatile bool hostMounted = false;
volatile bool filesystemBusy = false;  // Prevent USB MSC writes racing active SdFat reads.

const char SETTINGS_TXT[] = "settings.txt";
const char AUDIO_WAV[] = "audio.wav";

const char SSTV_JPEG_FILE[] = "sstv.jpg";
const char SSTV_JPEG_PREFIX[] = "sstv";
const char SSTV_JPEG_EXT[] = ".jpg";
const char AUDIO_SEQUENCE_PREFIX[] = "audio";
const char AUDIO_SEQUENCE_EXT[] = ".wav";
const char SONGS_TXT[] = "songs.txt";
const char APRS_MESSAGES_TXT[] = "messages.txt";
const char MORSE_MESSAGES_TXT[] = "morse.txt";
#define FILE_SEQUENCE_MAX 999U

#define SSTV_IMAGE_WIDTH 320
#define SSTV_IMAGE_HEIGHT 240

// 320 x 240 x 2 = 153,600 bytes.
static uint16_t sstvImage[SSTV_IMAGE_WIDTH * SSTV_IMAGE_HEIGHT];

JPEGDEC jpeg;
FatFile jpegRoot;
FatFile jpegFile;

int jpegSourceWidth = 0;
int jpegSourceHeight = 0;

volatile uint32_t sstvPixelBoundsErrors = 0;
volatile uint32_t sstvLastLineBoundsErrors = 0;

const char DEFAULT_CALLSIGN[12] = "";
const uint8_t DEFAULT_ITU_ZONE = 2;
const double DEFAULT_FREQ_MHZ = 146.565;
const uint8_t DEFAULT_DUTY_CYCLE = 100;
const uint8_t DEFAULT_WPM = 15;
const uint16_t DEFAULT_MORSE_TONE_HZ = 600;
const uint8_t DEFAULT_TONE_AMPLITUDE_PERCENT = 60;
const uint8_t DEFAULT_ATTENUATION = 0;
const uint8_t DEFAULT_ATTENUATION_MODE = ATTENUATION_MODE_FIXED;
const uint8_t DEFAULT_ATTENUATION_MIN = 0;
const uint8_t DEFAULT_ATTENUATION_MAX = 127;
const bool DEFAULT_APRS_ENABLE = false;
const bool DEFAULT_FREQUENCY_SHIFTING = true;
const bool DEFAULT_MORSE_MESSAGE_ENABLE = false;

// Built-in fallback tune. Replaces the old embedded PCM audio.h waveform.
const char DEFAULT_RTTTL[] =
  "PicoFox:d=4,o=4,b=150:"
  "g,b,g,b,g,b,g,b,g,b,g,b,"
  "g,b,g,b,g,b,g,b,g,b,g,b,"
  "g,b,g,b,g,b,g,b,g,b,g,b";

const int32_t CARRIER_OFFSET_SEQUENCE_HZ[] = {
  0, 1000, 3000, 5000, 3000, 1000,
  0, -1000, -3000, -5000, -3000, -1000
};

// SSTV timing diagnostics. Keep the type near the top because Arduino's
// .ino preprocessor may generate prototypes before later declarations.
struct SstvTimingStats {
  uint32_t updates;
  uint64_t totalUpdateUs;
  uint32_t minUpdateUs;
  uint32_t maxUpdateUs;
  uint32_t missedDeadlines;
  uint32_t frameStartUs;
  uint32_t frameEndUs;
};

struct SstvPllEntry {
  uint8_t reg[8];
};

struct AudioPllEntry {
  uint8_t reg[8];
};

struct SstvRgb {
  uint8_t r;
  uint8_t g;
  uint8_t b;
};

struct Settings {
  char callsign[12];
  uint8_t ituZone;
  double transmitFreqMHz;
  uint8_t dutyCyclePercent;
  uint8_t morseWPM;
  uint16_t morseToneHz;
  uint8_t toneAmplitudePercent;
  bool isConfigured;

  // Attenuator configuration. Values are limited to 0..127.
  uint8_t attenuation;
  uint8_t attenuationMode;
  uint8_t attenuationMin;
  uint8_t attenuationMax;

  // Normal audio.wav + Morse callsign transmission.
  // Set VOICE_ENABLE=0 for SSTV-only operation.
  bool voiceEnabled;
  uint8_t audioMode;
  bool frequencyShiftingEnabled;
  bool morseMessageEnabled;

  // SSTV configuration.
  bool sstvEnabled;
  uint8_t sstvMode;

  // APRS message configuration.
  bool aprsEnabled;
};

Settings settings = {
  .callsign = "",
  .ituZone = DEFAULT_ITU_ZONE,
  .transmitFreqMHz = DEFAULT_FREQ_MHZ,
  .dutyCyclePercent = DEFAULT_DUTY_CYCLE,
  .morseWPM = DEFAULT_WPM,
  .morseToneHz = DEFAULT_MORSE_TONE_HZ,
  .toneAmplitudePercent = DEFAULT_TONE_AMPLITUDE_PERCENT,
  .isConfigured = false,
  .attenuation = DEFAULT_ATTENUATION,
  .attenuationMode = DEFAULT_ATTENUATION_MODE,
  .attenuationMin = DEFAULT_ATTENUATION_MIN,
  .attenuationMax = DEFAULT_ATTENUATION_MAX,
  .voiceEnabled = DEFAULT_VOICE_ENABLE,
  .audioMode = DEFAULT_AUDIO_MODE,
  .frequencyShiftingEnabled = DEFAULT_FREQUENCY_SHIFTING,
  .morseMessageEnabled = DEFAULT_MORSE_MESSAGE_ENABLE,
  .sstvEnabled = DEFAULT_SSTV_ENABLE,
  .sstvMode = DEFAULT_SSTV_MODE,
  .aprsEnabled = DEFAULT_APRS_ENABLE
};


// DDS phase. Keeping phase continuous across SSTV frequency changes avoids
// unnecessary discontinuities at pixel/timing boundaries.
double sstvPhase = 0.0;

SstvTimingStats sstvStats = {0, 0, 0xFFFFFFFFUL, 0, 0, 0, 0};

SstvPllEntry sstvPllTable[SSTV_PLL_TABLE_LEVELS];
bool sstvPllTableReady = false;
int32_t sstvPllCarrierOffsetHz = 0;
uint32_t sstvPllWriteErrors = 0;

// Real-time SSTV fast path.
// The expensive floating-point sine and PLL-table mapping are precomputed.
// During transmission each modulation update only:
//   1. reads a PLL table index from the sine LUT,
//   2. writes the 8-byte PLL block over I2C,
//   3. advances a 32-bit phase accumulator.
uint16_t sstvSinePllIndex[256];
uint32_t sstvTonePhaseIncrement[256];
uint32_t sstvPhase32 = 0;

// Separate 8 kHz normal-audio modulation state. This deliberately does not
// share the SSTV lookup tables, preserving the known-good SSTV core.
AudioPllEntry audioPllTable[AUDIO_PLL_TABLE_LEVELS];
uint16_t audioSinePllIndex[256];
uint32_t audioPhase32 = 0;
int32_t audioPllCarrierOffsetHz = 0;
uint32_t audioPllWriteErrors = 0;

// State used only by RANDOM attenuation mode.
uint8_t lastRandomAttenuation = 0xFF;
uint32_t attenuationRandomState = 0x6D2B79F5UL;

// Recent actual RF-on durations used for duty-cycle averaging.
uint32_t dutyTxHistory[DUTY_AVERAGE_WINDOW] = {0};
uint8_t dutyTxHistoryCount = 0;
uint8_t dutyTxHistoryIndex = 0;
uint64_t dutyTxHistorySum = 0;

// -----------------------------------------------------------------------------
// Forward declarations
// -----------------------------------------------------------------------------

void formatFat16();
void saveDefaultSettings();
void ensureSettingsComments();
void setSi5351Output(bool enabled);
void setFrequencyOffset(double deviation);
void programAttenuator(uint8_t attenuation);
uint32_t nextAttenuationRandom();
uint8_t selectAttenuationForTransmit();
uint32_t playAudio(const char* filename, int32_t carrierOffsetHz);
uint32_t playRtttl(const char* rtttl, int32_t carrierOffsetHz);
uint32_t sendMorseText(const char* text, int32_t carrierOffsetHz);
uint32_t sendMorseCallsign(int32_t carrierOffsetHz);
bool buildAudioPllTable(int32_t carrierOffsetHz);
bool writeAudioPllEntry(uint16_t index);
void buildAudioSineTable(uint8_t amplitudePercent);
uint32_t audioPhaseIncrementForTone(uint16_t toneHz);
uint32_t sendAudioTone(uint16_t toneHz, uint32_t durationUs, uint8_t amplitudePercent);
void sendAudioSilence(uint32_t durationUs);
void audioTask();

// SSTV stages 3-4.
void sendSSTVTone(uint16_t toneHz, uint32_t durationUs, int32_t carrierOffsetHz);
void sendRobot36VIS(int32_t carrierOffsetHz);
void sendRobot36Jpeg(const char* filename, int32_t carrierOffsetHz);
uint16_t getSstvPixelSafe(uint16_t x, uint16_t line);
bool flashFileExists(const char* filename);
void ensureSongsFilePresent();
bool getNextRtttlSong(uint16_t* songIndex, String* outSong);
void ensureAprsMessagesFilePresent();
void ensureMorseMessagesFilePresent();
bool getNextMorseMessage(uint16_t* messageIndex, String* outMessage);
bool getNextAprsMessage(uint16_t* messageIndex, String* outMessage);
bool readFatFileLine(FatFile* f, String* outLine);
bool nextSequencedFile(const char* prefix,
                       const char* extension,
                       uint16_t* index,
                       char* outName,
                       size_t outNameSize);
uint32_t playNextNormalTransmission(uint8_t* carrierSequenceStep,
                                    uint16_t* audioSequenceIndex,
                                    uint16_t* songSequenceIndex,
                                    uint16_t* morseMessageIndex);
uint32_t sendNextSstvTransmission(uint8_t* carrierSequenceStep,
                                  uint16_t* sstvSequenceIndex);
uint32_t sendNextAprsTransmission(uint8_t* carrierSequenceStep,
                                  uint16_t* messageIndex);
bool parseAx25Callsign(const char* text, char call[7], uint8_t* ssid, char display[10]);
void encodeAx25Address(uint8_t out[7], const char* call, uint8_t ssid, bool last);
uint16_t ax25FcsUpdate(uint16_t crc, uint8_t data);
void aprsSendNrziBit(uint8_t bit, bool* toneMark, uint32_t* sampleRemainder,
                     uint32_t* nextDeadlineUs, uint32_t* samplesSent);
void aprsSendFlag(bool* toneMark, uint32_t* sampleRemainder,
                  uint32_t* nextDeadlineUs, uint32_t* samplesSent);
void aprsSendStuffedByte(uint8_t value, uint8_t* onesCount, bool* toneMark,
                         uint32_t* sampleRemainder, uint32_t* nextDeadlineUs,
                         uint32_t* samplesSent);
uint32_t sendAprsMessage(const char* message, int32_t carrierOffsetHz);
uint32_t updateAverageTxTime(uint32_t activeLengthMs);
void applyDutyCycleOff(uint32_t activeLengthMs, uint32_t minimumOffMs = 0);
bool loadRobot36Jpeg(const char* filename);
void* jpegOpenCallback(const char* filename, int32_t* fileSize);
void jpegCloseCallback(void* handle);
int32_t jpegReadCallback(JPEGFILE* handle, uint8_t* buffer, int32_t length);
int32_t jpegSeekCallback(JPEGFILE* handle, int32_t position);
int jpegDrawCallback(JPEGDRAW* draw);
void resetSstvTimingStats();
void recordSstvUpdateTime(uint32_t updateUs, uint32_t sampleBudgetUs);
void reportSstvTimingStats();
void calculateSstvPllRegisters(int32_t totalOffsetHz, uint8_t out[8]);
bool buildSstvPllTable(int32_t carrierOffsetHz);
bool writeSstvPllEntry(uint16_t index);
void setFastSstvDeviation(double audioDeviationHz);
void buildSstvRealtimeTables();
static inline void writeFastSstvSample(uint32_t phaseIncrement);
static inline uint32_t phaseIncrementForTone(uint16_t toneHz);
void preconvertSstvFramebuffer();

// -----------------------------------------------------------------------------
// Filesystem
// -----------------------------------------------------------------------------

void formatFat16() {
  uint8_t workbuf[4096];
  formatter.format(&flash, workbuf);

  if (fatfs.begin(&flash, true, 1, 0)) {
    Serial.println("Flash formatted with a new FAT filesystem.");
  } else {
    Serial.println("Flash formatting failed.");
    while (true) {
      delay(1000);
    }
  }
}

int32_t mscReadCb(uint32_t lba, void* buffer, uint32_t bufsize) {
  return flash.readBlocks(lba, (uint8_t*)buffer, bufsize / 512) ? bufsize : -1;
}

int32_t mscWriteCb(uint32_t lba, uint8_t* buffer, uint32_t bufsize) {
  // Tell the playback core to get out of the filesystem before the host
  // modifies FAT sectors underneath it.
  hostMounted = true;

  // playAudio() checks hostMounted every sample, so this should normally
  // clear within a few hundred microseconds. Give it some margin.
  uint32_t waitStart = millis();
  while (filesystemBusy && (millis() - waitStart) < 100) {
    delayMicroseconds(100);
  }

  // If the firmware still owns an open filesystem object, fail this WRITE10
  // rather than corrupting the volume. The host can retry.
  if (filesystemBusy) {
    return -1;
  }

  return flash.writeBlocks(lba, buffer, bufsize / 512) ? bufsize : -1;
}

void mscFlushCb() {
  flash.syncBlocks();

  // The host has changed FAT sectors behind SdFat's back. Drop cached
  // filesystem data so it can never be reused as though it were current.
  fatfs.cacheClear();
}

bool openRoot() {
  return root.openRoot(&fatfs);
}

void closeRoot() {
  root.close();
}

void saveDefaultSettings() {
  char buffer[3072];

  snprintf(
    buffer,
    sizeof(buffer),
    "# Alphanumeric callsign, maximum 12 characters.\n"
    "CALLSIGN=%s\n"
    "\n"
    "# ITU zone where the transmitter operates. Valid values: 1, 2, or 3.\n"
    "ITU_ZONE=%u\n"
    "\n"
    "# Transmit frequency in MHz.\n"
    "FREQ_MHZ=%.6f\n"
    "\n"
    "# Transmit duty cycle percentage, valid range 0 to 100.\n"
    "# If SSTV mode is enabled, this must be less than 80.\n"
    "DUTY_CYCLE=%u\n"
    "\n"
    "# Attenuation mode: FIXED uses the ATTENUATION setting; RANDOM selects a random value each TX.\n"
    "ATTENUATION_MODE=FIXED\n"
    "\n"
    "# ATTENUATION setting used when ATTENUATION_MODE=FIXED. Valid range: 0 to 127, approximately 0.25 dB per step.\n"
    "ATTENUATION=%u\n"
    "\n"
    "# ATTENUATION_MIN is the lowest value used in RANDOM mode. Valid range: 0 to 127, approximately 0.25 dB per step.\n"
    "# ATTENUATION_MIN must be less than ATTENUATION_MAX.\n"
    "ATTENUATION_MIN=%u\n"
    "\n"
    "# ATTENUATION_MAX is the highest value used in RANDOM mode. Valid range: 0 to 127, approximately 0.25 dB per step.\n"
    "# ATTENUATION_MAX must be greater than ATTENUATION_MIN.\n"
    "ATTENUATION_MAX=%u\n"
    "\n"
    "# Morse ID speed in words per minute. Valid range: 1 to 60 WPM.\n"
    "MORSE_WPM=%u\n"
    "\n"
    "# Morse tone frequency in Hz. Valid range: 100 to 2000 Hz.\n"
    "MORSE_TONE=%u\n"
    "\n"
    "# Morse tone volume percentage. Valid range: 1 to 100.\n"
    "MORSE_TONE_VOL=%u\n"
    "\n"
    "# Enables Morse messages from morse.txt instead of the CALLSIGN-only ID. 1=enabled, 0=disabled.\n"
    "# morse.txt uses one message per line and rotates through the list.\n"
    "# If VOICE_ENABLE=0 and this is 1, the transmitter sends only the Morse message and CALLSIGN.\n"
    "MORSE_MESSAGE_ENABLE=%u\n"
    "\n"
    "# Enables WAV/RTTTL audio playback only. 1=enabled, 0=disabled.\n"
    "VOICE_ENABLE=%u\n"
    "\n"
    "# Selects the normal audio source. Valid values: WAV or RTTTL.\n"
    "# WAV uses audio.wav, audio1.wav, audio2.wav, etc.\n"
    "# RTTTL uses one song per line from songs.txt and rotates through the list.\n"
    "# RTTTL format and example songs:\n"
    "# https://1j01.github.io/rtttl.js/\n"
    "# https://github.com/neverfa11ing/FlipperMusicRTTTL\n"
    "AUDIO_MODE=WAV\n"
    "\n"
    "# Enables Frequency Shifting for Voice/WAV/RTTTL transmissions only. 1=enabled, 0=disabled.\n"
    "# This setting never affects SSTV or APRS.\n"
    "FREQUENCY_SHIFTING=1\n"
    "\n"
    "# Enables SSTV mode. 1=enabled, 0=disabled.\n"
    "# You MUST set DUTY_CYCLE to less than 80 for SSTV mode to work correctly.\n"
    "SSTV_ENABLE=%u\n"
    "\n"
    "# SSTV encoding mode. Currently ONLY ROBOT36 is supported.\n"
    "SSTV_MODE=ROBOT36\n"
    "\n"
    "# Enables APRS message transmissions. 1=enabled, 0=disabled. Messages are read from messages.txt.\n"
    "APRS_ENABLE=%u\n",
    DEFAULT_CALLSIGN,
    DEFAULT_ITU_ZONE,
    DEFAULT_FREQ_MHZ,
    DEFAULT_DUTY_CYCLE,
    DEFAULT_ATTENUATION,
    DEFAULT_ATTENUATION_MIN,
    DEFAULT_ATTENUATION_MAX,
    DEFAULT_WPM,
    DEFAULT_MORSE_TONE_HZ,
    DEFAULT_TONE_AMPLITUDE_PERCENT,
    DEFAULT_MORSE_MESSAGE_ENABLE ? 1 : 0,
    DEFAULT_VOICE_ENABLE ? 1 : 0,
    DEFAULT_FREQUENCY_SHIFTING ? 1 : 0,
    DEFAULT_SSTV_ENABLE ? 1 : 0,
    DEFAULT_APRS_ENABLE ? 1 : 0
  );

  if (!file.open(&root, SETTINGS_TXT, O_RDWR | O_CREAT | O_TRUNC)) {
    Serial.println("Failed to create default settings.txt");
    return;
  }

  file.write(buffer, strlen(buffer));
  file.close();
}
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
void loop() {
  // Main core remains available for USB/TinyUSB work handled by the core.
}

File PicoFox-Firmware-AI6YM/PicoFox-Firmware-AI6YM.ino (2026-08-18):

/* PicoFox - 2M FM Fox Transmitter

Copyright 2025 Giorgi Enterprises LLC dba AI6YM.radio.
License: Creative Commons Attribution-NonCommercial-ShareAlike 4.0 International (see LICENSE file).

COMMERCIAL USE OF THIS CODE AND ANY DERIVATIVE IS FORBIDDEN WITHOUT PERMISSION FROM THE COPYRIGHT HOLDER!

You may configure this software without compiling and flashing. Simply connect the device to your PC with a USB cable and edit the
settings.txt file. You may also change the audio which is played between morse code IDs by replacing the audio.wav file. The file you
provide MUST be 5kHz sampling, unsigned 16bit PCM audio.

The device may be reset to factory settings by deleting the settings.txt and audio.wav files. In factory settings the device WILL NOT
transmit. Configuring a callsign is required to enable the transmitter.
*/

#include <Arduino.h>
#include <Wire.h>
#include <si5351.h>
#include "SPI.h"
#include "SdFat_Adafruit_Fork.h"
#include "Adafruit_SPIFlash.h"
#include "Adafruit_TinyUSB.h"

#include "audio.h"

// #define DEBUG 1

// Board revision ID pins.
// Pulldown required. 0000 == r2, 1000 == r3.
#define ID0 22u
#define ID1 23u
#define ID2 24u
#define ID3 25u

#define SDA 0u                                  // I2C data pin.
#define SCL 1u                                  // I2C clock pin.
#define I2C_CLOCK_HZ 1000000                    // >= 800kHz needed for sufficiently fast I2C writes.
#define AMP_EN 2u                               // Pin which enables the amplifier. Set LOW to enable, HIGH to disable.
#define ATTN_LE 4u                              // Pin which latches the attenuator.
#define AUDIO_SAMPLE_RATE_HZ 5000               // Audio sample rate (also rate of updates to SI5351).
#define FM_DEVIATION_HZ 10000                   // Maximum RF deviation in Hz.
#define SI5351_PLL SI5351_PLLA                  // PLL which will be used on the SI5351, consider this PLL unavailable for other purposes.
#define SI5351_CLOCK_OUTPUT SI5351_CLK0         // Clock output which drives RF circuitry.
#define SI5351_PLL_HZ 900000000                 // PLL frequency in Hz.
#define SI5351_MS_MAX_DENOM 1048575             // 2^20 - 1, max denominator for fractional MS divider.
#define SI5351_MS_RATIONAL_CALC_ITERS 16        // Maximum iterations searching for MS parameters, keeps calculation within 200us.

#define SI5351_CLOCK_PARAM_START 42             // Register address on which multisynth parameters start.
#define SI5351_CLOCK_DIV 6                      // Fixed divider between PLL clock and MS.
#define SI5351_DRIVE_LEVEL_R2 SI5351_DRIVE_2MA  // Power output from SI5351, higher levels don't add much output but do create spurious emmissions.
#define SI5351_DRIVE_LEVEL_R3 SI5351_DRIVE_2MA  // Power output from SI5351.
#define SAMPLE_WRITE_CORR_US -3                 // Time correction between sample writes to account for code which can't be measured.
#define MAX_UINT32 4294967295                   // Maximum value for a 32 bit unsigned integer. Used to prevent glitches when micros() overflows.

#define TEST_MODE_PIN 14u                       // Pin which is monitored to enter test mode. If you use this pin feel free to remove this logic.

// Frequency limitations.
#define MIN_FREQ_MHZ 144
#define MAX_FREQ_MHZ_ITU1 146  // ITU zone 1.
#define MAX_FREQ_MHZ 148       // ITU zones 2 and 3.

// Test mode detected. Indicates program / test before shipping.
bool test_mode;

// Board revision.
uint16_t revision;
bool wireRunning = false;

// RF Clock Gen
Si5351 si5351;

// Uses same external flash chip that the RP2040 is executing from. Size depends on Tools -> Flash Size setting.
Adafruit_FlashTransport_RP2040 flashTransport;
Adafruit_SPIFlash flash(&flashTransport);

// Filesystem and file descriptors.
FatFormatter formatter;
FatVolume fatfs;
FatFile root;
FatFile file;

// Controller for USB mass storage device.
Adafruit_USBD_MSC usb_msc;
bool hostMounted = false;

// Flash file names.
const char SETTINGS_TXT[] = "settings.txt";
const char AUDIO_WAV[] = "audio.wav";
const char CALLSIGN_WAV[] = ".callsign.wav";
const char SETTINGS_CRC[] = ".settings_crc.bin";

// Default settings.
const char DEFAULT_CALLSIGN[12] = "";
const uint8_t DEFAULT_ITU_ZONE = 2;
const double DEFAULT_FREQ_MHZ = 146.565;
const uint8_t DEFAULT_DUTY_CYCLE = 100;
const uint8_t DEFAULT_WPM = 15;
const uint8_t DEFAULT_FARNSWORTH_WPM = 10;
const uint16_t DEFAULT_MORSE_TONE_HZ = 600;
const uint8_t DEFAULT_TONE_AMPLITUDE_PERCENT = 70;
const uint8_t DEFAULT_ATTENUATION = 0;
const uint8_t ATTENUATION_CYCLE_OFFSETS[] = {0, 40, 20};
const int32_t CARRIER_OFFSET_SEQUENCE_HZ[] = {0, 1000, 3000, 5000, 3000, 1000, 0, -1000, -3000, -5000, -3000, -1000};

// Config struct, start by loading defaults.
struct Settings {
  char callsign[12];
  uint8_t ituZone;
  double transmitFreqMHz;
  uint8_t dutyCyclePercent;
  uint8_t morseWPM;
  uint8_t farnsworthWPM;
  uint16_t morseToneHz;
  uint8_t toneAmplitudePercent;
  bool isConfigured;
  uint8_t attenuation;
};

Settings settings = {
  .callsign = { *DEFAULT_CALLSIGN },
  .ituZone = DEFAULT_ITU_ZONE,
  .transmitFreqMHz = DEFAULT_FREQ_MHZ,
  .dutyCyclePercent = DEFAULT_DUTY_CYCLE,
  .morseWPM = DEFAULT_WPM,
  .farnsworthWPM = DEFAULT_FARNSWORTH_WPM,
  .morseToneHz = DEFAULT_MORSE_TONE_HZ,
  .isConfigured = (strlen(DEFAULT_CALLSIGN) > 0),
  .attenuation = DEFAULT_ATTENUATION
};

int settingsCrc = 0;

struct MsABC {
  uint32_t A;
  uint32_t B;
  uint32_t C;
  Si5351RegSet reg;
  uint8_t int_mode;
};

// Creates a fat16 filesystem in the flash space.
void formatFat16(void) {
  uint8_t workbuf[4096];
  formatter.format(&flash, workbuf);
  if (fatfs.begin(&flash, true, 1, 0)) {
    Serial.println("Flash chip successfully formatted with new empty filesystem!");
  } else {
    Serial.println("Formatting failed. Good luck friend.");
    while (true)
      ;
  }
}

// Reads data from flash device.
int32_t mscReadCb(uint32_t lba, void* buffer, uint32_t bufsize) {
  return flash.readBlocks(lba, (uint8_t*)buffer, bufsize / 512) ? bufsize : -1;
}

// Writes data to the flash device.
int32_t mscWriteCb(uint32_t lba, uint8_t* buffer, uint32_t bufsize) {
  hostMounted = true;
  return flash.writeBlocks(lba, buffer, bufsize / 512) ? bufsize : -1;
}

// Flushes writes to flash.
void mscFlushCb(void) {
  flash.syncBlocks();
}

bool openRoot() {
  return root.openRoot(&fatfs);
}

void closeRoot() {
  root.close();
}
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

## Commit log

2026-08-07 Rev3 updates.
    [Enclosure Body.stl, PicoFox-PCB.kicad_pcb, PicoFox-PCB.kicad_sch]
2026-08-18 Initial commit with SSTV support
    This is the initial commit that supports SSTV, and file switching.
    Includes first pass of the new badge-style fox for Pacificon - HAS NOT BEEN TESTED YET.
    **** THIS CODE CONTAINS A LOT OF AI. PLEASE READ THE README.MD ****
    Things changed/added to firmware:
    - Add SSTV_ENABLE, SSTV_MODE, and VOICE_ENABLE settings
    - Support SSTV-only and alternating voice/SSTV operation
    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
    [PicoFox-PCB.kicad_pcb, PicoFox-PCB.kicad_sch, picofox-bom.csv]
2026-08-18 Adding a complied/fixed version of AI6YM's code
    Due to difficulty issues with building, including pre-built packages, and AI6YM's origional code with some fixes.
    [PicoFox-Firmware-AI6YM.ino]
2026-08-28 Minor updates
    Adding AI6YM firmware with fix for forced format of filesystem. Updated PCB/Gerbers.
    [PicoFox-PCB-B_Cu.gbr, PicoFox-PCB-B_Mask.gbr, PicoFox-PCB-B_Paste.gbr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]
2026-08-28 Add RTTTL Support and APRS Support
    - Add AUDIO_MODE setting with WAV and RTTTL modes
    - Add songs.txt RTTTL song bank support
    - Cycle through RTTTL songs one line at a time and wrap to the first song
    - Ignore blank lines and lines beginning with #
    - Auto-create songs.txt with the built-in PicoFox RTTTL tune when missing
    - Add FatFile-compatible line reader for songs.txt
    - Remove MORSE_FARNSWORTH_WPM support
    - Use standard PARIS Morse timing based only on MORSE_WPM
    - Add live Morse generation after WAV and RTTTL playback
    - Remove dependency on audio.h
    - Add 100 ms TX key-up delay before audio transmissions
    - Add 1 second keyed carrier gap between normal audio and Morse ID
    - Reduce RTTTL modula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
    [PicoFox-Firmware.ino]
2026-08-31 Add Frequency shift customization, Tweak audio/deviation to be more consistant
    - Reduced RTTTL modulation amplitude from 100% to 65% to reduce distortion and over-deviation.
    - Restored the Si5351 PLL to the unmodulated carrier after APRS transmission before disabling RF.
    - Added configurable Frequency Shifting:
    FREQUENCY_SHIFTING=1 or 0
    - Frequency shifting now applies ONLY to Voice/WAV/RTTTL transmissions.
    - SSTV always remains exactly on FREQ_MHZ.
    - APRS always remains exactly on FREQ_MHZ and no longer advances the carrier-shift sequence.
    - Increased the maximum configurable MORSE_WPM from 30 to 60 WPM.
    - Reduced RTTTL and Morse tone amplitude from to 60%. to help make all the audio soun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
    [PicoFox-Firmware.ino]
